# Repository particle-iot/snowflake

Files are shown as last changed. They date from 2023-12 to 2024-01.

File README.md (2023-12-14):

# Particle Snowflake

Welcome to the repository for the Particle Snowflake
, a limited edition [Particle P2](https://store.particle.io/products/p2-wi-fi-module-cut-tape-x10) powered PCBA in the form of a snowflake. The Snowflake provides a seasonal light show and plays a classic holiday tune.

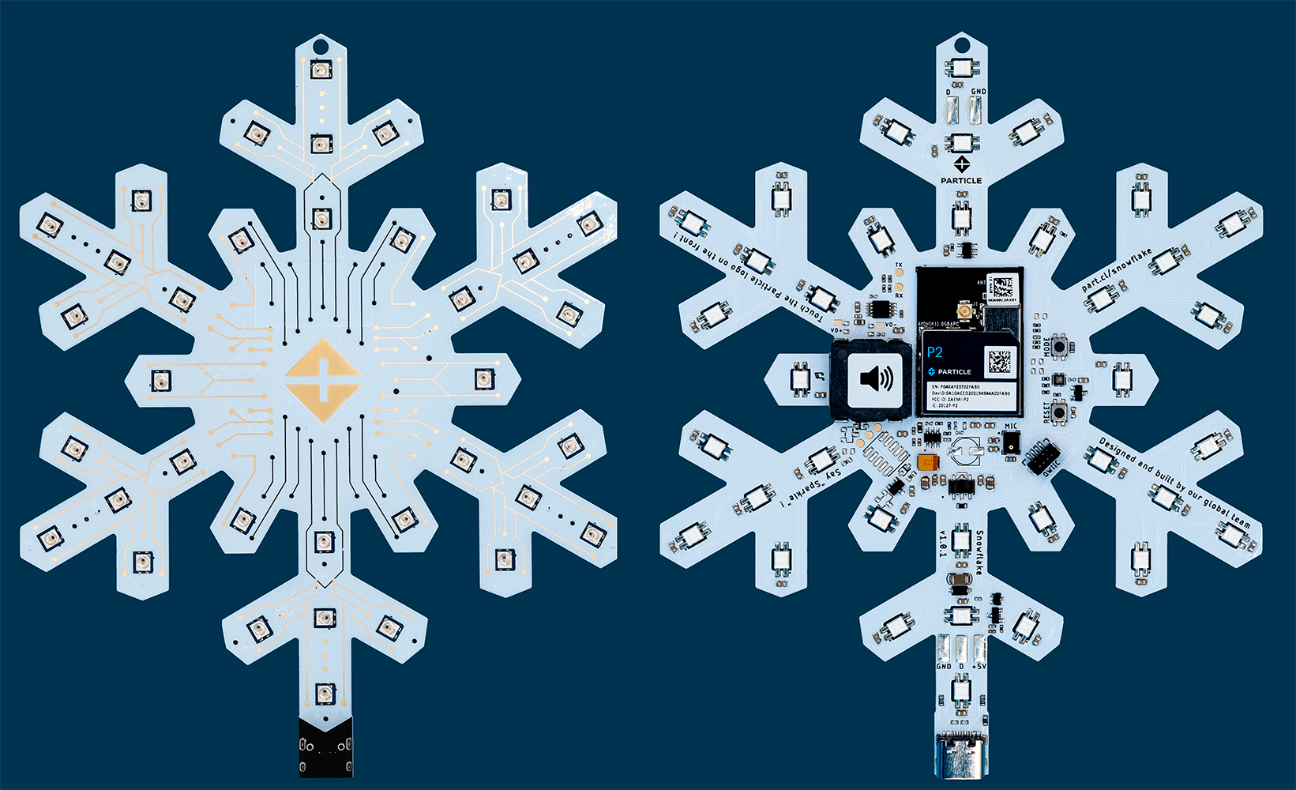
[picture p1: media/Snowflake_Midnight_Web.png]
PCBA


This repository contains all of the firmware and hardware assets required to build the Particle Snowflake.

## Features

The Particle Snowflake has the following components to provide a complete experience straight out of the box:

- 36 individually addressable RGB LEDs to create various colors, patterns, and effects
- Onboard speaker to play festive tunes
- PDM microphone to enable additional features

## Repository Contents

This repository consists of a firmware folder, a hardware folder, and an assets folder.

### Firmware Folder

The firmware folder contains the source code and MP3 asset files that drive the operation of the Particle Snowflake. These include:

- Source code for the application firmware
- Various libraries to support the LEDs, audio and MP3 playback, capacitive touch button drivers, etc.
- MP3 asset files with preloaded message and holiday song

### Hardware Folder

The hardware folder contains detailed design files that can be used for manufacturing the Particle Snowflake. These include:

- Schematic files for the PCBA
- BRD files for the PCBA
- [A comprehensive Bill of Materials (BOM)](./hardware/schematic-pcb/snowflake-hw-v1.0.1/snowflake v1.01 Bom .xlsx)
- Illustrator files for the silkscreen artwork

### Asset Folder

The asset folder contains images and a video illustrating various aspects of the Particle Snowflake. These include:

- [Front of PCBA](./media/Snowflake_Front_Midnight.png)
- [Back of PCBA](./media/Snowflake_Back_Midnight.png)
- [Video of the various light patterns](./media/Snowflake_Action.mp4)

## Usage

Feel free to use these designs as a reference for creating your own Particle Snowflake or use them directly in your designs. 

## Contributing

As an open-source project, we encourage contributions and suggestions. If you have an idea for an improvement or notice a bug, please open an issue or submit a pull request.

## License

This project is open source and available under the [Apache License 2.0](LICENSE).

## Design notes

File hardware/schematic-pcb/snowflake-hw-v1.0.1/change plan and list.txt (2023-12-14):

PCB
done 1, all points were changed from 0.6mm to 0.9 mm 
done 2, Add www.particle.io - size 40mil
done 3, Add the Particle with the logo - biggest size possible
done 4, Reduce the size of the label snowflake v0.0.2 to 40mil
done 5. Fix music symbol 
done 6. Adding in a hole in the PCB at the top to allow someone to put a little ornament hook (linked) through to hang on a tree?
done 7, Chang the Version to  Snowflake 1.0.1
done 8, Move P2 1.5 mm to the left
9, Check USB d+d-  impedance 
10. put the text “Hello” on one of the snowflake arms
11. Text 1  Designed and built by our global team
12. Text 2   Say “Sparkle” !
13. Touch the Particle logo on the front !
done 14. Particle Logo and Name: 
done 15，finish artwork silk-screen and soldermask

sch 
done 1, Change R26 to NC
done 2, Change R25 to  pull-up
done 3, Delete R13
done 4, Add 2  Jump  resistance for Speaker VO- VO+,  Default short connection in PCB,  can cut it off with a knife if you want to open the Speaker
done 5, Add 2  FS-1540

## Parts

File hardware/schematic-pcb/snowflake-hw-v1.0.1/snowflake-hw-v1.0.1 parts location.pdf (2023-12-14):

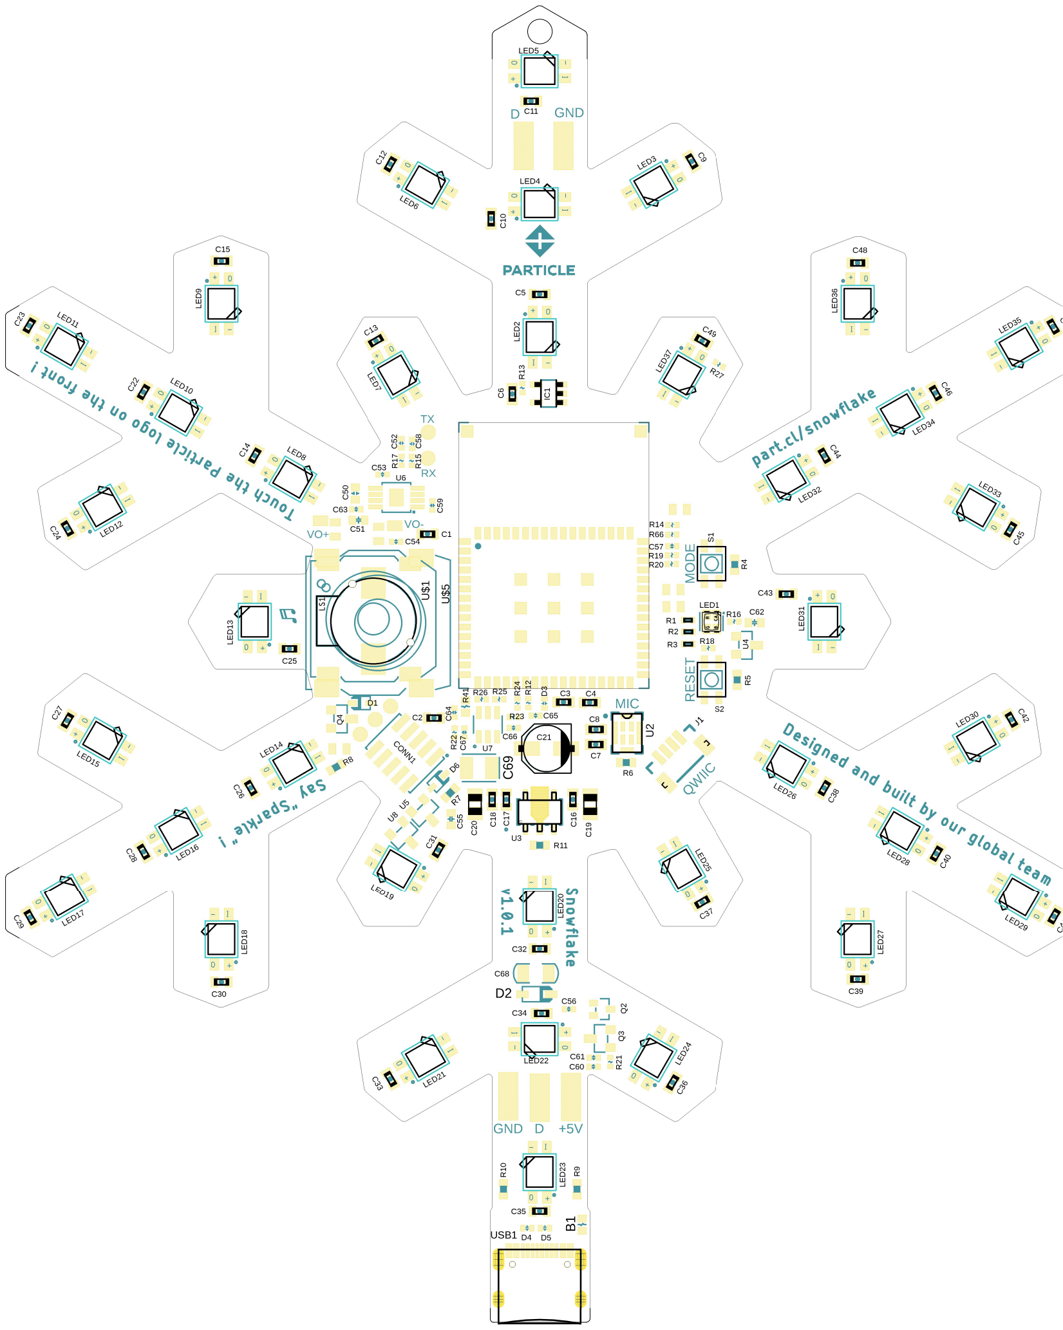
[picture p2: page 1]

C23 C29

LED5

C41

47

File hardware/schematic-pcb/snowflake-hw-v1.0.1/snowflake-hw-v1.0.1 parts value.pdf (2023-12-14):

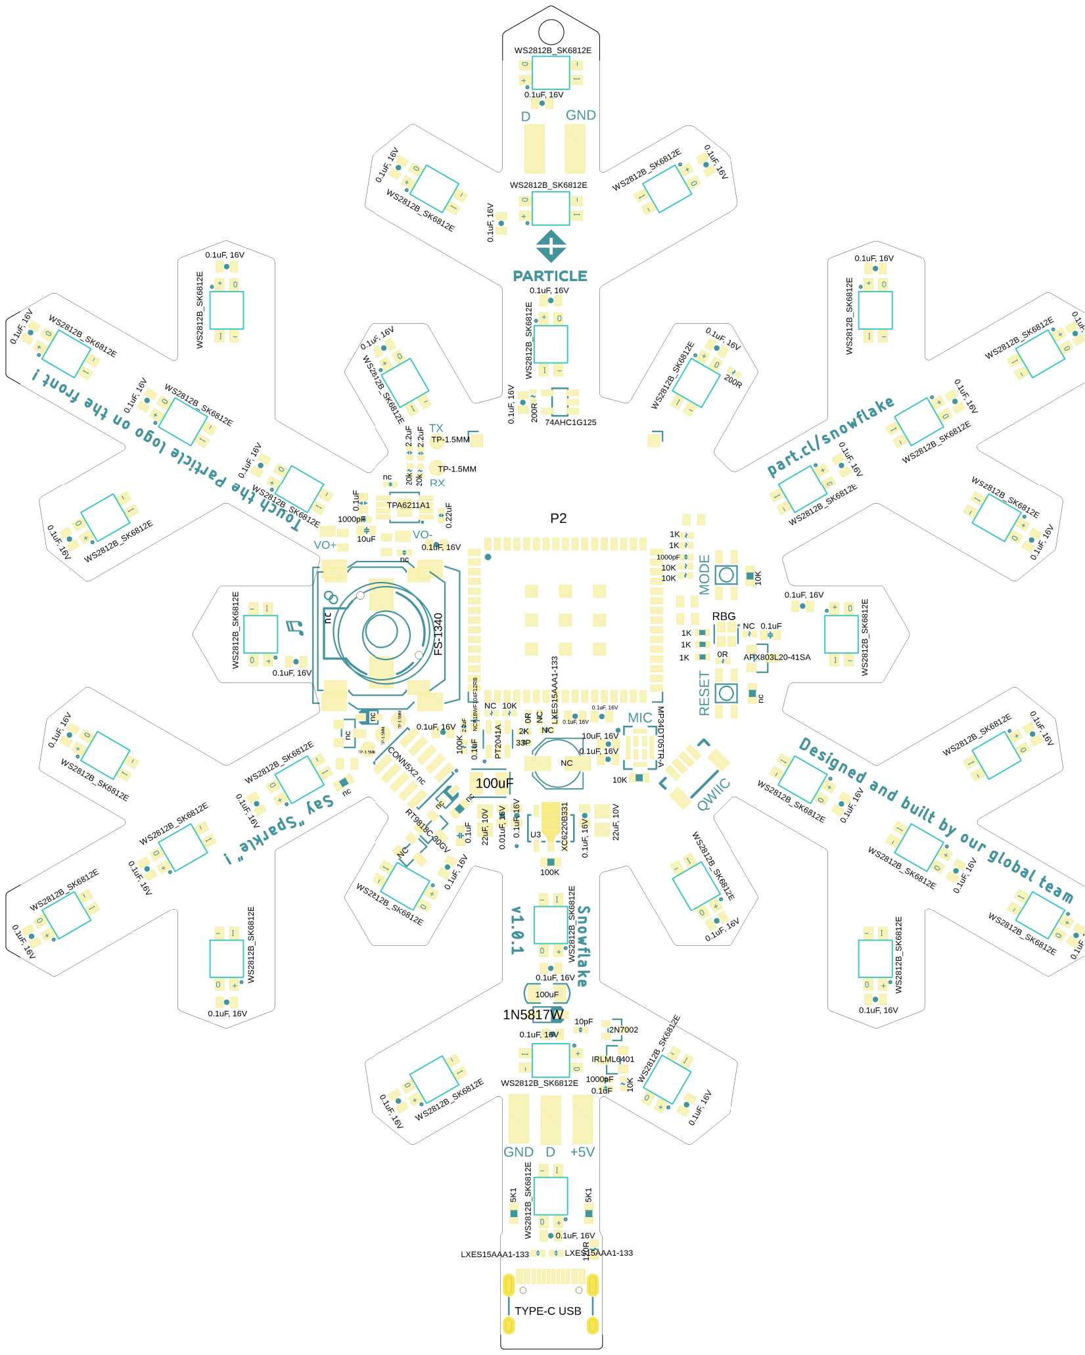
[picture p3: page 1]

0.1uF, 1

0.1uF,

WS2812B_SK6812E

0.1uF, 16V

0.1uF, 16V

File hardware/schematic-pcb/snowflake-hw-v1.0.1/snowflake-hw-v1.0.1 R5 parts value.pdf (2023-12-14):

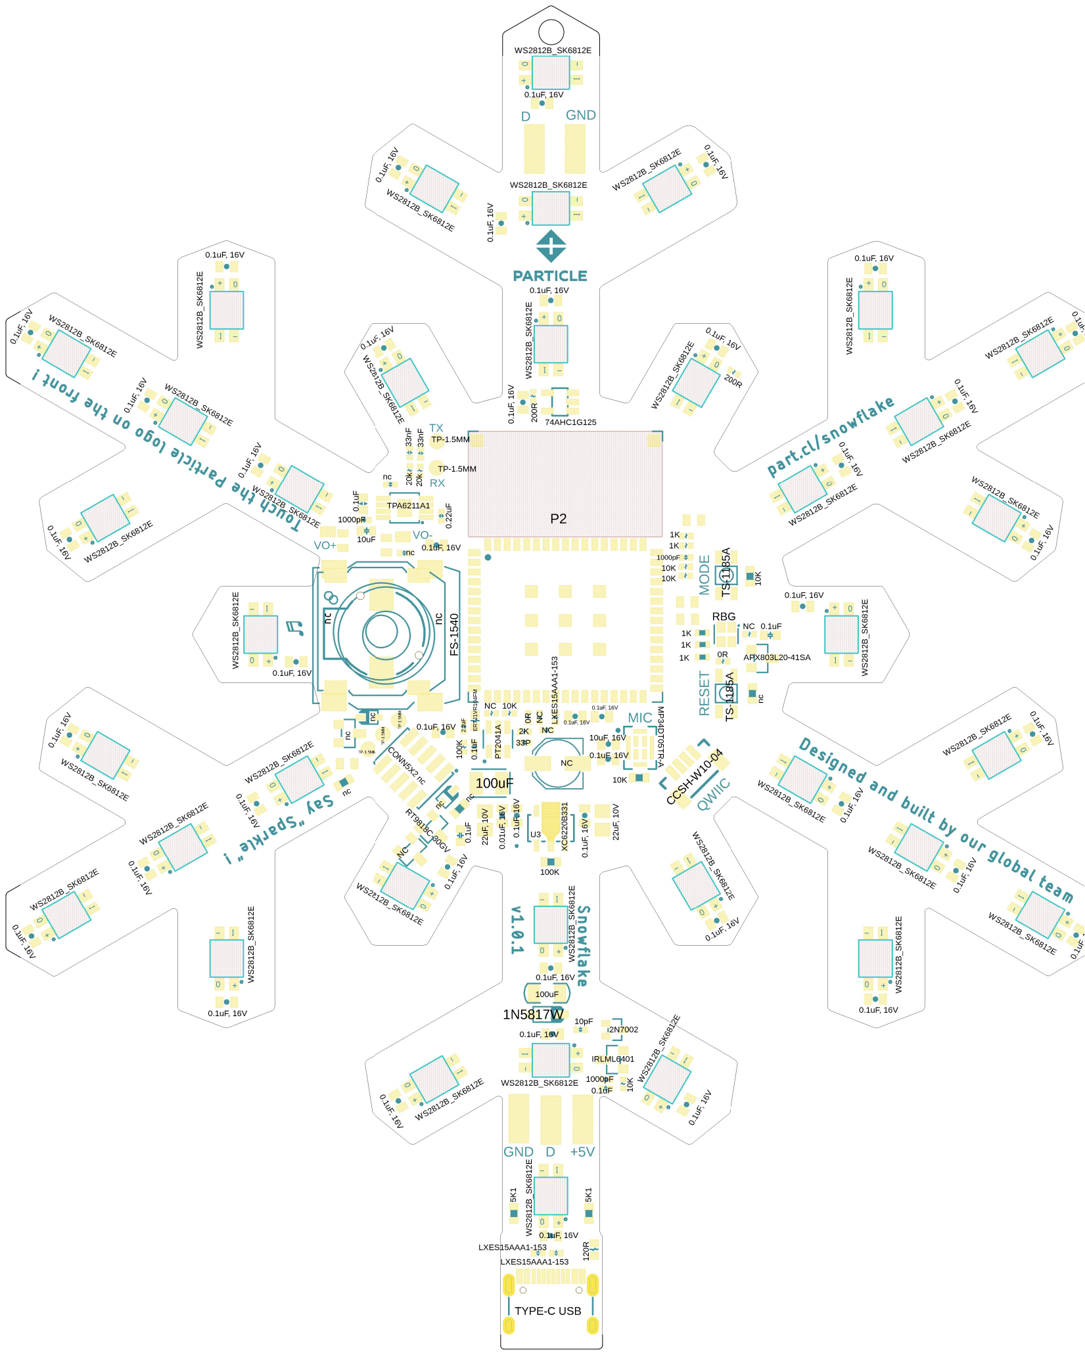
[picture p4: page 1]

0.1uF, 1

0.1uF,

WS2812B_SK6812E

0.1uF, 16V

0.1uF, 16V

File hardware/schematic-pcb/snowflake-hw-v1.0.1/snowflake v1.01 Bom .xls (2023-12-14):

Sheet: Sheet1
Part | list e | xported | from Y:/work/snowflake/SCH | and PCB/snowflake-hw-v1.0.1/贴 | 片图/sno | wf | lake-hw-v1.0.1 R5.sch at 2023/11/9 上午11:26
Qty | Value |  | Device | Package | Parts |  |  | Descript | ion COLOR COPYRIGHT
1 |  |  | CONN_04SMD4 | JST04_1MM_VERT | J1 |  |  | Multi co | nnection point. Often used as Generic Header-pin footprint for 0.1 inch spaced/style header connections BLACK
2 |  |  | TAC_SWITCHSMD | TACTILE_SWITCH_SMD | S1, S2 |  |  | SMD Tact | iile Switch
1 |  |  | USB_C16PIN | USB-C-16P | USB1 |  |  | USB Type | C 16Pin Connector
1 | 0.01uF | , 16V | CAP_0.01UF_25V_0603 | C0603_P | C18 |  |  | Particle | Capacitors
2 | 0.1uF |  | CAP0402 | C-0402 | C60, C67 |  |  | CAP
2 | 0.1uF |  | CAP0603A | C-0603A | C55, C62 |  |  | CAP
1 | 0.1uF |  | CAPC0603 | C0603 | C50 |  |  | CAP
44 | 0.1uF, | 16V | CAP_0.1UF_16V_0603 | C0603_P | C1, C2, C | 3, | C4, C5, C6, C7, C9, C10, C11, C12, C13, C14, C15, C16, C17, C22, C23, C24, C25, C26, C27, C28, C29, C30, C31, C32, C33, C34, C35, C36, C37, C38, C39, C40, C41, C42, C43, C44, C45, C46, C47, C48, C49 | Particle | Capacitors
1 | 0.22uF |  | CAP0402 | C-0402 | C59 |  |  | CAP
2 | 0R |  | RES0402S | R-0402S | R18, R24 |  |  | RES
3 | 1000pF |  | CAP0402 | C-0402 | C57, C61, | C | 63 | CAP
1 | 100K |  | RES0402S | R-0402S | R22 |  |  | RES
1 | 100K |  | RES_100K_0603 | R0603_P | R11 |  |  | Particle | Resistors
1 | 100uF |  | CAP-ECASE_B | CASE-B | C69
1 | 100uF |  | CAPC1206 | C1206 | C68 |  |  | CAP
4 | 10K |  | RES0402S | R-0402S | R19, R20, | R | 21, R25 | RES
2 | 10K |  | RES_10K_0603 | R0603_P | R4, R6 |  |  | Particle | Resistors
1 | 10pF |  | CAP0402 | C-0402 | C56 |  |  | CAP
1 | 10uF |  | CAP0603A | C-0603A | C51 |  |  | CAP
1 | 10uF, | 16V | CAP_10UF_16V_0603 | C0603_P | C8 |  |  | Particle | Capacitors
1 | 120R |  | L | R-0603A | B1
2 | 1K |  | RES0402S | R-0402S | R14, R66 |  |  | RES
3 | 1K |  | RES_1K_0402 | R0402_P | R1, R2, R | 3 |  | Particle | Resistors
1 | 1N5817 | W | DIODESOD123 | SOD-123 | D2 |  |  | DIODE
1 | 2.2uF |  | CAP0402 | C-0402 | C64 |  |  | CAP
2 | 200R |  | RES0402S | R-0402S | R13, R27 |  |  | RES
2 | 20k |  | RES0402S | R-0402S | R15, R17 |  |  | RES
2 | 22uF, | 10V | C-EUC0805 | C0805 | C19, C20 |  |  | CAPACITO | R, European symbol
1 | 2K |  | RES0402S | R-0402S | R23 |  |  | RES
1 | 2N7002 |  | NMOSSOT323 | SOT323 | Q2 |  |  | NMOS
1 | 33P |  | CAP0402 | C-0402 | C66 |  |  | CAP
2 | 33nF |  | CAP0402A | C0402 | C52, C58 |  |  | CAP
2 | 5K1 |  | RES_0603 | R0603_P | R9, R10 |  |  | Particle | Resistors
1 | 74AHC1 | G125 | 74AHC1G125 | SOT23-5L | IC1
1 | APX803 | L20-41S | A APX803XXX-XXSASOT-2 | 3 SOT-23 | U4
1 | CONN5X | 2 nc | CONN5X2 | CONN5X2_1.27 | CONN1 |  |  | 5x2 pin | JTAG connector for Particle mesh dev kits
1 | ERTJ1V | R104FM | RESR0603A | R-0603A | R41 |  |  | RES
1 | FS-154 | 0 | SEPAKER15X15MM | KLJ-01504T | U$5
1 | IRLML6 | 401 | PMOS | SOT-23 | Q3 |  |  | PMOS
6 | JMP_06 | 03_NC | JMP_0603_NC | JMP_0603_NC | U$2, U$3, | U | $4, U$6, U$7, U$15
3 | LXES15 | AAA1-15 | 3 ESD | C0402 | D3, D4, D | 5
1 | MP34DT | 05TR-A | MP34DT05TR-A | MP34DT05TR-A_STM | U2 |  |  |  | Copyright (C) 2023 Ultra Librari
1 | NC |  | APX803XXX-XXSASOT-2 | 3 SOT-23 | U8
1 | NC |  | CAP0402 | C-0402 | C65 |  |  | CAP
1 | NC |  | CPOL-USC | PANASONIC_C | C21 |  |  | POLARIZE | D CAPACITOR, American symbol
3 | NC |  | RES0402S | R-0402S | R12, R16, | R | 26 | RES
1 | NC |  | SEPAKER | KJL-01304T(13X13MM) | U$1
1 | P2 |  | P2 | P2 | U1 |  |  | Particle | P2
1 | PT2041 | A | PT2041A | SOT-23-6 | U7
1 | RGB-LE | D-CLMVB | #NAME? | B PLCC4-2MM-RGB | LED1 |  |  | CREE CLM | VB-FKA RGB LED 2mm x 2mm
1 | RT9818 | C-30GV | RT9818C | SOT-23 | U5
5 | TP-1.5 | MM | TP-1.5MM | TP | TP1, TP5, | T | P6, TP7, TP8
2 | TP1.0X | 1.5 | TP1.0X1.5 | TP-1.0X1.5 | VO+, VO-
5 | TP2X5M | M | TP2X5MM | TP_2X5MM | +5V_EX, D | AT | A, DATA1, GND, GND115
1 | TPA621 | 1A1 | TPA6211A1 | MSOP-8 | U6
36 | WS2812 | B_SK681 | 2E WS2812B_SK6812E | NEO3535_REVERSE | LED2, LED | 3, | LED4, LED5, LED6, LED7, LED8, LED9, LED10, LED11, LED12, LED13, LED14, LED15, LED16, LED17, LED18, LED19, LED20, LED21, LED22, LED23, LED24, LED25, LED26, LED27, LED28, LED29, LED30, LED31, LED32, LED33, LED34, LED35, LED36, LED37
1 | XC6220 | B331PR- | G XC6220B331PR-GSOT-8 | 9-5_TOR-M SOT-89-5_TOR-M | U3 |  |  |  | Copyright (C) 2022 Ultra Librari
1 | nc |  | BUZZER-SMD | BUZZER-CCV | LS1 |  |  | Buzzer
2 | nc |  | CAP0402 | C-0402 | C53, C54 |  |  | CAP
2 | nc |  | DIODESOD323 | SOD-323 | D1, D6 |  |  | DIODE
1 | nc |  | NMOSSOT-23 | SOT-23 | Q4 |  |  | NMOS
1 | nc |  | RES_100K_0603 | R0603_P | R8 |  |  | Particle | Resistors
1 | nc |  | RES_10K_0603 | R0603_P | R5 |  |  | Particle | Resistors
1 | nc |  | RES_1K_0603 | R0603_P | R7 |  |  | Particle | Resistors

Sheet: SNOWFLAKE-PCBA MO bom R2
Item Export
Run by
Name: Vincent Li
Email: vincent@particle.io
Workspace: Particle IO Production
Date: Nov 08, 2023
Run Description: Item Number:SNOWFLAKE-PCBA, Item Name:Holiday Snowflake PCBA, Revision:3
level | item_number | item_name | item_category | quantity | reference_designator | bom_notes | vendor_1 | vendor item number_1 | manufacturer_1 | manufacturer_item_number_1 | manufacturer_2 | manufacturer_item_number_2 | sub_type | sub_rank
0 | SNOWFLAKE-PCBA | Holiday Snowflake PCBA | Printed Circuit Board Assembly
1 | 120-00014 | CAP CER 100UF 10V X5R 1206 20% | Capacitor | 1 | C68 |  |  |  | Murata Electronics | GRM31CR61A107ME05L
1 | 120-00066 | CAP CER 220nF 16V X7R 0402 10% | Capacitor | 1 | C59 |  |  |  | Fenghua (HK) Electronics Ltd. | 0402B224K160NT
1 | 120-00067 | CAP CER 33nF 50V X7R 10% 0402 | Capacitor | 2 | C52,C58 |  |  |  | YAGEO | CC0402KRX7R9BB333
1 | 125-00021 | CONN HEADER SMD 4POS 1MM | Connector | 1 | J1 |  | Kaweei Technology Co Limited | CCSH-W10-04-BK-RC | Kaweei Technology Co Limited | CCSH-W10-04-BK-RC
1 | 140-00053 | DIGITAL RGB LED 0.2W 3.2x2.8x1.8mm SMD middle board mount | Diode | 36 | LED2,LED3,LED4,LED5,LED6,LED7,LED8,LED9,LED10,LED11,LED12,LED13,LED14,LED15,LED16,LED17,LED18,LED19,LED20,LED21,LED22,LED23,LED24,LED25,LED26,LED27,LED28,LED29,LED30,LED31,LED32,LED33,LED34,LED35,LED36,LED37 |  |  |  | Dongguan OPSCO Optoelectronics Co.,LTD | SK6812MINI-E
1 | 140-00055 | TVS DIODE 4VWM 0.05pF@1MHz 0402 | Diode | 3 | D3,D4,D5 |  |  |  | Murata Electronics | LXES15AAA1-153
1 | 150-00067 | IC BUFFER NON-INVERT 6V SC74A/SOT-753 | IC | 1 | IC1 |  |  |  | Nexperia USA Inc. | 74HC1G125GV,125
1 | 150-00068 | MIC MEMS DIGITAL PDM OMNI -26DB | IC | 1 | U2 |  |  |  | STMicroelectronics | MP34DT05TR-A
1 | 150-00069 | IC TOUCH SENSOR 1KEY SOT23-6 | IC | 1 | U7 |  |  |  | PinTeng Technology Co.,Ltd | PT2041AT6
1 | 150-00070 | IC SUPERVISOR 1 CHANNEL SOT23-3 | IC | 1 | U5 |  |  |  | Richtek USA Inc. | RT9818C-30GV
1 | 150-00071 | IC REG LINEAR 3.3V 1A SOT89-5 | IC | 1 | U3 |  |  |  | Torex Semiconductor Ltd | XC6220B331PR-G
1 | 150-00072 | IC AMP CLASS AB MONO 3.1W 8MSOP | IC | 1 | U6 |  |  |  | Texas Instruments | TPA6211A1DGNR
1 | 150-00073 | IC SUPERVISOR 1 CHANNEL SOT23-3 | IC | 1 | U4 |  |  |  | Diodes Incorporated | APX803L20-41SA-7
1 | 160-00013 | SPEAKER 8OHM 0.5W MAX TOP PORT 87DB SMD | Misc. Electrical | 1 | U$5 |  |  |  | Taizhou Fu Sheng Electronic Technology Co., Ltd. | FS-1540
1 | 175-00048 | FR-4 PCB 138.8x112.6x1.6mm Tg150 4layers, 1/0.5/0.5/1oz, WHT oil, BLK silk, ENIG | Printed Circuit Board | 1
1 | 180-00049 | RES 5.1K OHM 1% 1/10W 0603 | Resistor | 2 | R9,R10 |  |  |  | YAGEO | RC0603FR-075K1L
1 | P2REEL | P2 Wi-Fi Module, Reel [x600] | Final Assembly | 1 | U1 |  |  |  | Wistron Neweb Corporation | 81DHSK11.G01
1 | PC-201501 | SMD 16PIN TYPE-C USB2.0 | Connector | 1 | USB1 |  |  |  | ZHAOJIN - EUV Electronics Co., Ltd | EUT-S009-BN-B-R
1 | PT-200001 | RES SMD 100K OHM 1% 1/16W 0402 | Resistor | 1 | R22 |  |  |  | YAGEO | RC0402FR-07100KL
1 | PT-200002 | RES SMD 1K OHM 5% 1/16W 0402 | Resistor | 5 | R1,R2,R3,R14,R66 |  |  |  | Fenghua (HK) Electronics Ltd. | RC-02W102JT | YAGEO | RC0402JR-071KP
1 | PT-200020 | Tactile Switch, Black Button 1.8mm height | Switch | 2 | S1,S2 |  |  |  | HAOYU (HONG KONG) LIMITED | TS-1185A-020C
1 | PT-200082 | CAP CER 0.1uF 16V X7R 0603 10% | Capacitor | 47 | C1,C2,C3,C4,C5,C6,C7,C9,C10,C11,C12,C13,C14,C15,C16,C17,C22,C23,C24,C25,C26,C27,C28,C29,C30,C31,C32,C33,C34,C35,C36,C37,C38,C39,C40,C41,C42,C43,C44,C45,C46,C47,C48,C49,C50,C55,C62 |  |  |  | Fenghua (HK) Electronics Ltd. | 0603B104K160NT
1 | PT-200110 | CAP CER 10nF 50V X7R 0603 10% | Capacitor | 1 | C18 |  | ABO Electronics (SHENZHEN) Co. Ltd | PT-200110 | Fenghua (HK) Electronics Ltd. | 0603B103K500NT
1 | PT-200139 | CAP CER 10uF 16V X5R 0603 20% | Capacitor | 2 | C8,C51 |  | ABO Electronics (SHENZHEN) Co. Ltd | PT-200139 | Fenghua (HK) Electronics Ltd. | 0603X106M160NT
1 | PT-200184 | CAP CER 2.2uF 6.3V X5R 0402 10% Low ESR<70mohms | Capacitor | 1 | C64 |  | UNIVERSAL MICROELECTRONICS CO.,LTD | PT-200184 | YAGEO | CC0402KRX5R5BB225
1 | PT-200197 | RES SMD 0R OHM 5% 1/16W 0402 | Resistor | 2 | R18,R24 |  |  |  | Fenghua (HK) Electronics Ltd. | RC-02000JT
1 | PT-200477 | RES SMD 10K OHM 1% 1/10W 0603 | Resistor | 2 | R4,R6 |  | ABO Electronics (SHENZHEN) Co. Ltd | PT-200477 | YAGEO | RC0603FR-0710KL
1 | PT-200690 | CAP CER 0.1UF 25V X7R 0402 20% | Capacitor | 2 | C60,C67 |  | ABO Electronics (SHENZHEN) Co. Ltd | PT-200690 | Murata Electronics | GRM155R71E104ME14
1 | PT-200691 | CAP CER 1000PF 50V C0G/NP0 0402 5% | Capacitor | 3 | C57,C61,C63 |  | ABO Electronics (SHENZHEN) Co. Ltd | PT-200691 | Murata Electronics | GRM1555C1H102JA01
1 | PT-200699 | CAP CER 22uF 10V X5R 0805 20% | Capacitor | 2 | C19,C20 |  | ABO Electronics (SHENZHEN) Co. Ltd | PT-200699 | YAGEO | CC0805MKX5R6BB226
1 | PT-200700 | NRND - CAP CER 33PF 50V C0G/NP0 0402 5% | Capacitor | 1 | C66 |  | ABO Electronics (SHENZHEN) Co. Ltd | PT-200700 | Murata Electronics | GRM1555C1H330JA01D
1 | PT-200705 | RES SMD 2K OHM 1% 1/16W 0402 | Resistor | 1 | R23 |  |  |  | YAGEO | RC0402FR-072KL
1 | PT-200708 | N-MOS 60V,115mA SC-70 ROHS | IC | 1 | Q2 |  |  |  | Leshan Radio Company, Ltd. | L2N7002WT1G
1 | PT-200709 | P-MOS -12V 4.3A SOT23 ROHS | IC | 1 | Q3 |  |  |  | Infineon Technologies | IRLML6401TRPBF
1 | PT-200722 | NRND - CAP CER 10pF 50V C0G(NP0 ) 0402 5% | Capacitor | 1 | C56 |  | ABO Electronics (SHENZHEN) Co. Ltd | PT-200722 | Murata Electronics | GRM1555C1H100JA01D
1 | PT-200805 | RES SMD 10K OHM 1% 1/16W 0402 | Resistor | 4 | R19,R20,R21,R25 |  | ABO Electronics (SHENZHEN) Co. Ltd | PT-200805 | YAGEO | RC0402FR-0710KL
1 | PT-200821 | LED RGB, Common Anode, Clear, 4PLCC SMD ROHS | Diode | 1 | LED1 |  |  |  | Cree Inc. | CLMVC-FKA-CA1E1L81BB7C3C3
1 | PT-200933 | RES SMD 20K OHM 1% 1/16W 0402 | Resistor | 2 | R15,R17 |  | ABO Electronics (SHENZHEN) Co. Ltd | PT-200933 | ABO Electronics (SHENZHEN) Co. Ltd | 0402WGF0203TCE
1 | PT-200934 | RES SMD 220R OHM 5% 1/16W 0402 | Resistor | 2 | R13,R27 |  |  |  | UNIROYAL ELECTRONICS INDUSTRY CO., LTD. | 0402WGJ0221TCE
1 | PT-201009 | Schottky Diode VF=0.45V SOD123F | Diode | 1 | D2 |  |  |  | JIANGSU CHANGJIANG ELECTRONICS TECHNOLOGY CO., LTD | B5817WL
1 | PT-201206 | RES SMD 100K OHM 1% 1/10W 0603 | Resistor | 1 | R11 |  |  |  | VISHAY | CRCW0603100KFKEA
1 | PT-201400 | FERRITE BEAD 120 OHM 0603 1LN | Inductor | 1 | B1 |  |  |  | Murata Electronics | BLM18PG121SZ1D
1 | PT-201487 | POLY TA SMD B case 100UF 6.3V 20% | Capacitor | 1 | C69 |  |  |  | AVX Corporation | TAJB107M006RNJ
1 | PT-201566 | THERM NTC 100KOHM 4200K 0603 1% | Resistor | 1 | R41 |  |  |  | Particle | ERTJ1VR104FM
Generated for Particle IO Production by Arena. All information contained in this document is proprietary and confidential.

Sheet: SNOWFLAKE-PCBA MO bom R1
Item Export
Run by
Name: Vincent Li
Email: vincent@particle.io
Workspace: Particle IO Production
Date: Nov 07, 2023
Run Description: Item Number:SNOWFLAKE-PCBA, Item Name:Holiday Snowflake PCBA, Revision:2
level | item_number | item_name | item_category | quantity | reference_designator | bom_notes | vendor_1 | vendor item number_1 | manufacturer_1 | manufacturer_item_number_1 | manufacturer_2 | manufacturer_item_number_2 | manufacturer_3 | manufacturer_item_number_3 | sub_type | sub_rank
0 | SNOWFLAKE-PCBA | Holiday Snowflake PCBA | Printed Circuit Board Assembly
1 | 120-00014 | CAP CER 100UF 10V X5R 1206 20% | Capacitor | 1 | C68 |  |  |  | Murata Electronics | GRM31CR61A107ME05L
1 | 120-00066 | CAP CER 220nF 16V X7R 0402 10% | Capacitor | 1 | C59 |  |  |  | Fenghua (HK) Electronics Ltd. | 0402B224K160NT
1 | 120-00067 | CAP CER 33nF 50V X7R 10% 0402 | Capacitor | 2 | C52,C58 |  |  |  | YAGEO | CC0402KRX7R9BB333
1 | 125-00021 | CONN HEADER SMD 4POS 1MM | Connector | 1 | J1 |  | Kaweei Technology Co Limited | CCSH-W10-04-BK-RC | Kaweei Technology Co Limited | CCSH-W10-04-BK-RC
1 | 140-00053 | DIGITAL RGB LED 0.2W 3.2x2.8x1.8mm SMD middle board mount | Diode | 36 | LED2,LED3,LED4,LED5,LED6,LED7,LED8,LED9,LED10,LED11,LED12,LED13,LED14,LED15,LED16,LED17,LED18,LED19,LED20,LED21,LED22,LED23,LED24,LED25,LED26,LED27,LED28,LED29,LED30,LED31,LED32,LED33,LED34,LED35,LED36,LED37 |  |  |  | Dongguan OPSCO Optoelectronics Co.,LTD | SK6812MINI-E
1 | 140-00055 | TVS DIODE 4VWM 0.05pF@1MHz 0402 | Diode | 3 | D3,D4,D5 |  |  |  | Murata Electronics | LXES15AAA1-153
1 | 150-00067 | IC BUFFER NON-INVERT 6V SC74A/SOT-753 | IC | 1 | IC1 |  |  |  | Nexperia USA Inc. | 74HC1G125GV,125
1 | 150-00068 | MIC MEMS DIGITAL PDM OMNI -26DB | IC | 1 | U2 |  |  |  | STMicroelectronics | MP34DT05TR-A
1 | 150-00069 | IC TOUCH SENSOR 1KEY SOT23-6 | IC | 1 | U7 |  |  |  | PinTeng Technology Co.,Ltd | PT2041AT6
1 | 150-00070 | IC SUPERVISOR 1 CHANNEL SOT23-3 | IC | 1 | U5 |  |  |  | Richtek USA Inc. | RT9818C-30GV
1 | 150-00071 | IC REG LINEAR 3.3V 1A SOT89-5 | IC | 1 | U3 |  |  |  | Torex Semiconductor Ltd | XC6220B331PR-G
1 | 150-00072 | IC AMP CLASS AB MONO 3.1W 8MSOP | IC | 1 | U6 |  |  |  | Texas Instruments | TPA6211A1DGNR
1 | 150-00073 | IC SUPERVISOR 1 CHANNEL SOT23-3 | IC | 1 | U4 |  |  |  | Diodes Incorporated | APX803L20-41SA-7
1 | 160-00013 | SPEAKER 8OHM 0.5W MAX TOP PORT 87DB SMD | Misc. Electrical | 1 | U$1 | 位置改为U$5 |  |  | Taizhou Fu Sheng Electronic Technology Co., Ltd. | FS-1540
1 | 175-00048 | FR-4 PCB 138.8x112.6x1.6mm Tg150 4layers, 1/0.5/0.5/1oz, WHT oil, BLK silk, ENIG | Printed Circuit Board | 1
1 | P2REEL | P2 Wi-Fi Module, Reel [x600] | Final Assembly | 1 | U1 |  |  |  | Wistron Neweb Corporation | 81DHSK11.G01
1 | PC-201501 | SMD 16PIN TYPE-C USB2.0 | Connector | 1 | X1 | 位置需要修改为USB1 |  |  | ZHAOJIN - EUV Electronics Co., Ltd | EUT-S009-BN-B-R
1 | PT-200001 | RES SMD 100K OHM 1% 1/16W 0402 | Resistor | 1 | R22 |  |  |  | YAGEO | RC0402FR-07100KL
1 | PT-200002 | RES SMD 1K OHM 5% 1/16W 0402 | Resistor | 3 | R1,R2,R3 | 增加R14, R66，数量改为5 |  |  | Fenghua (HK) Electronics Ltd. | RC-02W102JT | YAGEO | RC0402JR-071KP
1 | PT-200020 | Tactile Switch, Black Button 1.8mm height | Switch | 2 | S1,S2 |  |  |  | HAOYU (HONG KONG) LIMITED | TS-1185A-020C
1 | PT-200082 | CAP CER 0.1uF 16V X7R 0603 10% | Capacitor | 47 | C1,C2,C3,C4,C5,C6,C7,C9,C10,C11,C12,C13,C14,C15,C16,C17,C22,C23,C24,C25,C26,C27,C28,C29,C30,C31,C32,C33,C34,C35,C36,C37,C38,C39,C40,C41,C42,C43,C44,C45,C46,C47,C48,C49,C50,C55,C62 |  |  |  | Fenghua (HK) Electronics Ltd. | 0603B104K160NT
1 | PT-200087 | RES SMD 1K OHM 5% 1/10W 0603 | Resistor | 2 | R14,R66 | 删除，R14, R66改为0402封装 |  |  | Fenghua (HK) Electronics Ltd. | RS-03K102JT | Walsin Technology Corporation | WR06X102 JTL | YAGEO | RC0603JR-071KL
1 | PT-200110 | CAP CER 10nF 50V X7R 0603 10% | Capacitor | 1 | C18 |  | ABO Electronics (SHENZHEN) Co. Ltd | PT-200110 | Fenghua (HK) Electronics Ltd. | 0603B103K500NT
1 | PT-200139 | CAP CER 10uF 16V X5R 0603 20% | Capacitor | 2 | C8,C51 |  | ABO Electronics (SHENZHEN) Co. Ltd | PT-200139 | Fenghua (HK) Electronics Ltd. | 0603X106M160NT
1 | PT-200184 | CAP CER 2.2uF 6.3V X5R 0402 10% Low ESR<70mohms | Capacitor | 1 | C64 |  | UNIVERSAL MICROELECTRONICS CO.,LTD | PT-200184 | YAGEO | CC0402KRX5R5BB225
1 | PT-200197 | RES SMD 0R OHM 5% 1/16W 0402 | Resistor | 2 | R18,R24 |  |  |  | Fenghua (HK) Electronics Ltd. | RC-02000JT
1 | PT-200477 | RES SMD 10K OHM 1% 1/10W 0603 | Resistor | 2 | R4,R6 |  | ABO Electronics (SHENZHEN) Co. Ltd | PT-200477 | YAGEO | RC0603FR-0710KL
1 | PT-200690 | CAP CER 0.1UF 25V X7R 0402 20% | Capacitor | 2 | C60,C67 |  | ABO Electronics (SHENZHEN) Co. Ltd | PT-200690 | Murata Electronics | GRM155R71E104ME14
1 | PT-200691 | CAP CER 1000PF 50V C0G/NP0 0402 5% | Capacitor | 3 | C57,C61,C63 |  | ABO Electronics (SHENZHEN) Co. Ltd | PT-200691 | Murata Electronics | GRM1555C1H102JA01
1 | PT-200699 | CAP CER 22uF 10V X5R 0805 20% | Capacitor | 2 | C19,C20 |  | ABO Electronics (SHENZHEN) Co. Ltd | PT-200699 | YAGEO | CC0805MKX5R6BB226
1 | PT-200700 | NRND - CAP CER 33PF 50V C0G/NP0 0402 5% | Capacitor | 1 | C66 |  | ABO Electronics (SHENZHEN) Co. Ltd | PT-200700 | Murata Electronics | GRM1555C1H330JA01D
1 | PT-200705 | RES SMD 2K OHM 1% 1/16W 0402 | Resistor | 1 | R23 |  |  |  | YAGEO | RC0402FR-072KL
1 | PT-200708 | N-MOS 60V,115mA SC-70 ROHS | IC | 1 | Q2 |  |  |  | Leshan Radio Company, Ltd. | L2N7002WT1G
1 | PT-200709 | P-MOS -12V 4.3A SOT23 ROHS | IC | 1 | Q3 |  |  |  | Infineon Technologies | IRLML6401TRPBF
1 | PT-200722 | NRND - CAP CER 10pF 50V C0G(NP0 ) 0402 5% | Capacitor | 1 | C56 |  | ABO Electronics (SHENZHEN) Co. Ltd | PT-200722 | Murata Electronics | GRM1555C1H100JA01D
1 | PT-200805 | RES SMD 10K OHM 1% 1/16W 0402 | Resistor | 4 | R19,R20,R21,R25 |  | ABO Electronics (SHENZHEN) Co. Ltd | PT-200805 | YAGEO | RC0402FR-0710KL
1 | PT-200821 | LED RGB, Common Anode, Clear, 4PLCC SMD ROHS | Diode | 1 | LED1 |  |  |  | Cree Inc. | CLMVC-FKA-CA1E1L81BB7C3C3
1 | PT-200934 | RES SMD 220R OHM 5% 1/16W 0402 | Resistor | 2 | R13,R27 |  |  |  | UNIROYAL ELECTRONICS INDUSTRY CO., LTD. | 0402WGJ0221TCE
1 | PT-201009 | Schottky Diode VF=0.45V SOD123F | Diode | 1 | D2 |  |  |  | JIANGSU CHANGJIANG ELECTRONICS TECHNOLOGY CO., LTD | B5817WL
1 | PT-201206 | RES SMD 100K OHM 1% 1/10W 0603 | Resistor | 1 | R11 |  |  |  | VISHAY | CRCW0603100KFKEA
1 | PT-201400 | FERRITE BEAD 120 OHM 0603 1LN | Inductor | 1 | B1 |  |  |  | Murata Electronics | BLM18PG121SZ1D
1 | PT-201487 | POLY TA SMD B case 100UF 6.3V 20% | Capacitor | 1 | C69 |  |  |  | AVX Corporation | TAJB107M006RNJ
1 | PT-201531 | RES SMD 5.1K OHM 1% 1/16W 0402 | Resistor | 2 | R9,R10 | 要改用0603的料 |  |  | YAGEO | RC0402FR-075K1L
1 | PT-201566 | THERM NTC 100KOHM 4200K 0603 1% | Resistor | 1 | R41 |  |  |  | Particle | ERTJ1VR104FM
 |  | RES SMD 20K OHM 1% 1/16W 0402 | Resistor | 2 | R15, R17 | 增加
Generated for Particle IO Production by Arena. All information contained in this document is proprietary and confidential.

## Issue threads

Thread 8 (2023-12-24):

Builds & Flashes but doesn't Run

niabassey, 2023-12-24:
Building this from source in Particle Workbench gets as far as a successful build and flash and when the flash finishes the P2 even connects to WiFi, but that's it.  The LED animation stays frozen in it's last state and there no serial output (usually it give TFLite stats).

Flashing using https://setup.particle.io/?app=particle-snowflake brings it back up, but half the fun is getting to code this thing.

Are there particular build instructions to get a working locally built firmware image?

svanhoutte, 2023-12-25:
@niabassey How did you manage to compile, I get a SRAM overflowed. I m trying the 5.6.0 firmware, and code straight from the repo. I tried in the workbench and on docker same error.

> /root/.particle/toolchains/gcc-arm/10.2.1/bin/../lib/gcc/arm-none-eabi/10.2.1/../../../../arm-none-eabi/bin/ld: /workspace/target/workspace_fi.elf section `.bss' will not fit in region `SRAM'
/root/.particle/toolchains/gcc-arm/10.2.1/bin/../lib/gcc/arm-none-eabi/10.2.1/../../../../arm-none-eabi/bin/ld: region `SRAM' overflowed by 4 bytes
collect2: error: ld returned 1 exit status
make[1]: Leaving directory `/firmware/modules/tron/user-part'
make[1]: *** [/workspace/target/workspace_fi.elf] Error 1
make: *** [modules/tron/user-part] Error 2

niabassey, 2023-12-26:
I was able to compile on Windows but the application doesn't run.  I tried on Ubuntu and I got the same SRAM overflowed error :(

jhewitt0, 2024-01-04:
I'm unable to compile on Windows 11 using CLI or Workbench. Help please...

`particle compile p2 . --saveTo firmware.zip --target 5.5.0`
> Compile failed: Compiler timed out or encountered an error

If I tell Workbench to do a Cloud Compile I just get
> Compile failed: Compiler timed out or encountered an error
	at makeError (c:\Users\j_hew\.vscode\extensions\particle.particle-vscode-core-1.16.13\node_modules\execa\lib\error.js:59:11)
	at handlePromise (c:\Users\j_hew\.vscode\extensions\particle.particle-vscode-core-1.16.13\node_modules\execa\index.js:114:26)
	at process.processTicksAndRejections (node:internal/process/task_queues:95:5)

What is the correct way to compile the code?

Thanks

svanhoutte, 2024-01-04:
@jhewitt0 you should try a local compile from the bench.

mrlambchop, 2024-01-06:
Hey folks,

Apologies - there is a random bug in the makefile that breaks the compilation at semi-random.

We have a pending release that fixes this but it got stuck behind the holidays - not great timing I know.

To work around this, you can:

- clone device OS GitHub repo into a local folder
- git checkout -b fix/ram-calc-section-alignment origin/fix/ram-calc-section-alignment
- git submodules init
- git submodule update --recursive

Then open the project in Workbench and in the settings, set the setting:

Particle: Custom Device OSLocation to the path. Make sure the path is fully qualified.

Then in workbench, you can compile / flash the project and it won't randomly fail. I'll post back when the device OS release is out.

Thanks

Nick.

svanhoutte, 2024-01-08:
@mrlambchop I confirm the workaround works.
This link help to get the workbench setup. https://docs.particle.io/getting-started/developer-tools/workbench-faq/

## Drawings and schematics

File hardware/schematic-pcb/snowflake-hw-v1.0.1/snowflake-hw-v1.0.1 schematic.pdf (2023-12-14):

### FS-1340 nc

FS-1540

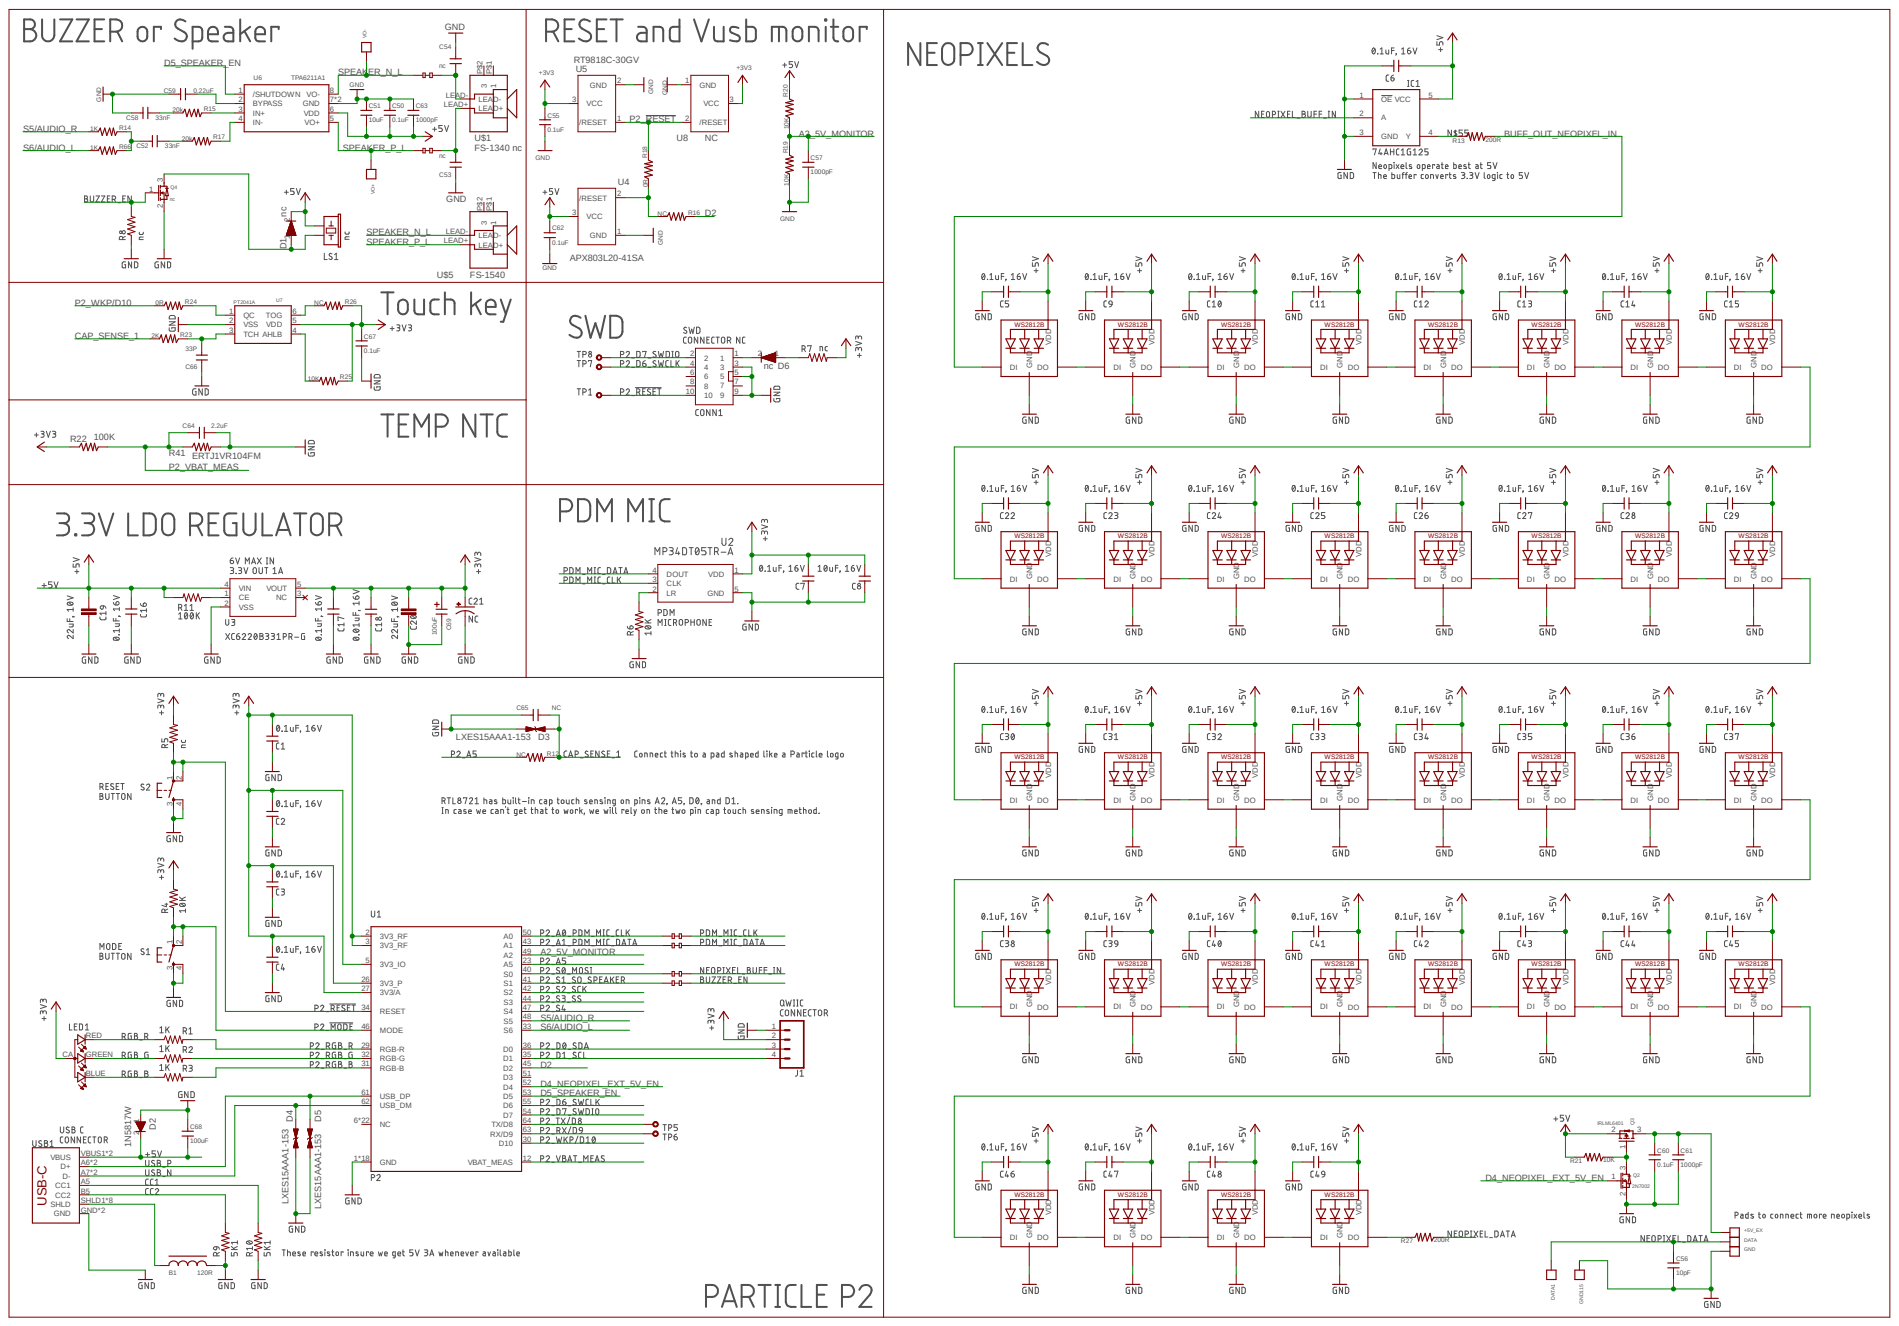
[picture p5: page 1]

DI GND DO VDD

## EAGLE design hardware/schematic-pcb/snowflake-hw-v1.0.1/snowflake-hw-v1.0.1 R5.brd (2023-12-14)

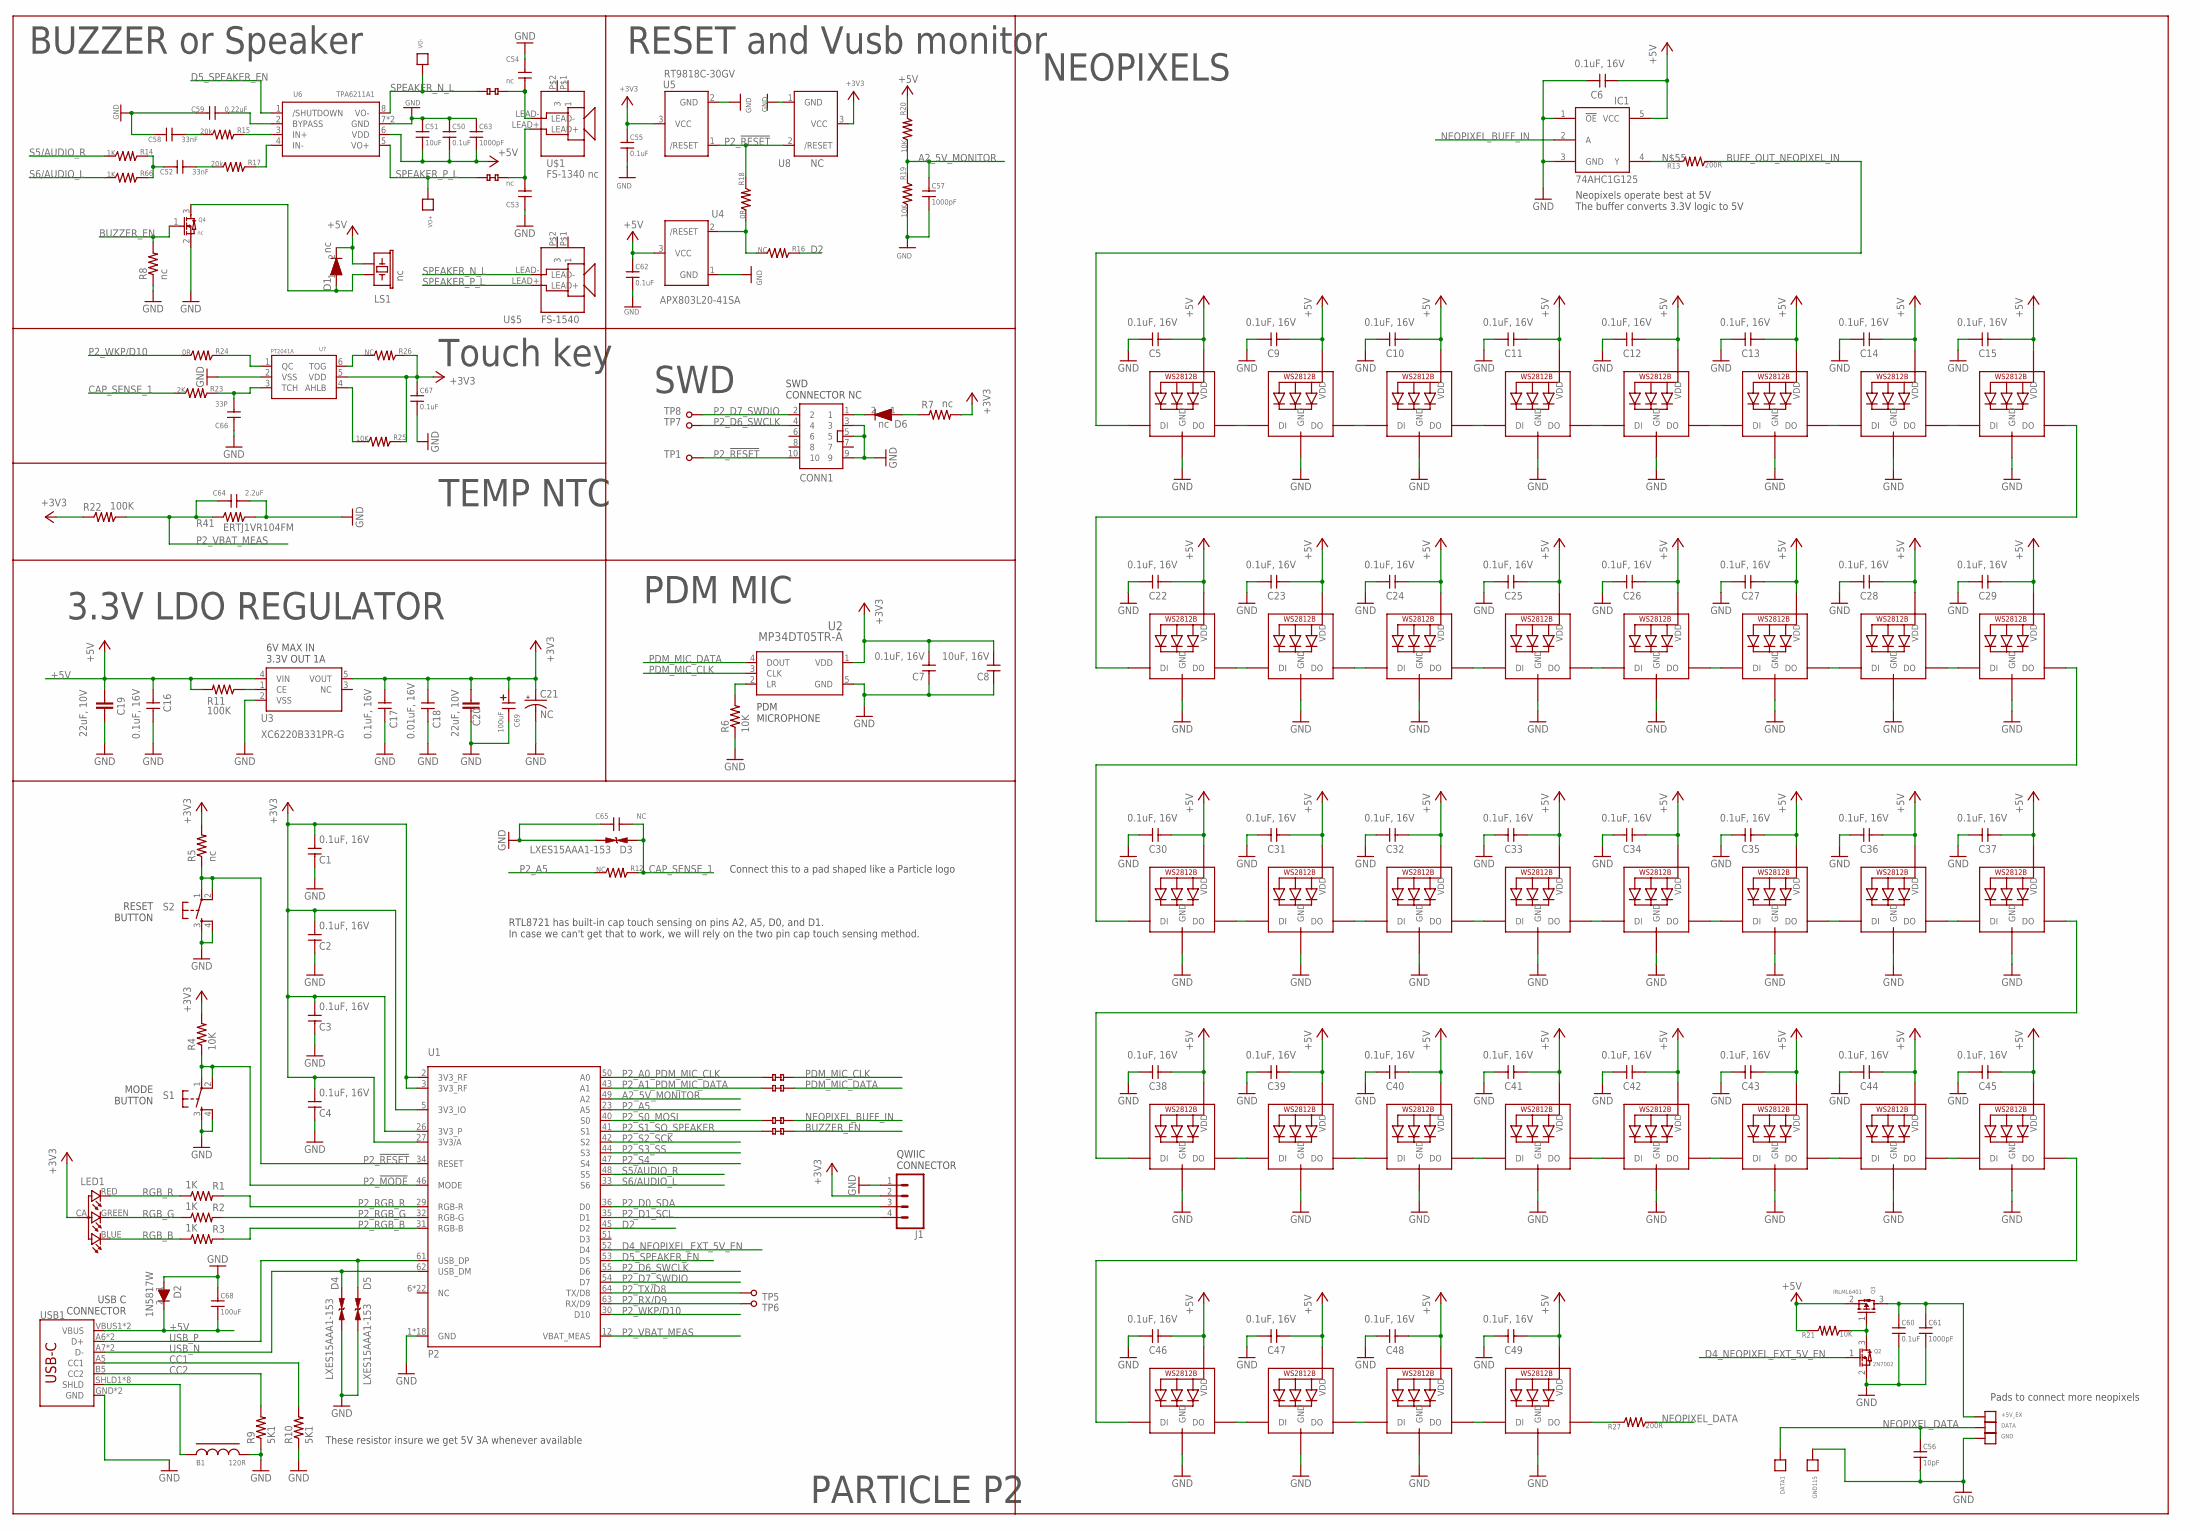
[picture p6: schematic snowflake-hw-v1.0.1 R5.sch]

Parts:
+5V_EX: TP2X5MM; TP_2X5MM
B1: 120R; R-0603A
C1, C2, C3, C4, C5, C6, C7, C9, C10, C11, C12, C13, C14, C15, C16, C17, C22, C23, C24, C25, C26, C27, C28, C29, C30, C31, C32, C33, C34, C35, C36, C37, C38, C39, C40, C41, C42, C43, C44, C45, C46, C47, C48, C49: 0.1uF, 16V; C0603_P
C8: 10uF, 16V; C0603_P
C18: 0.01uF, 16V; C0603_P
C19, C20: 22uF, 10V; C0805
C21: NC; PANASONIC_C
C50: 0.1uF; C0603
C51: 10uF; C-0603A
C52, C58: 33nF; C0402
C53, C54: nc; C-0402
C55, C62: 0.1uF; C-0603A
C56: 10pF; C-0402
C57, C61, C63: 1000pF; C-0402
C59: 0.22uF; C-0402
C60, C67: 0.1uF; C-0402
C64: 2.2uF; C-0402
C65: NC; C-0402
C66: 33P; C-0402
C68: 100uF; C1206
C69: 100uF; CASE-B
CONN1: CONN5X2 nc; CONN5X2_1.27
D1, D6: nc; SOD-323
D2: 1N5817W; SOD-123
D3, D4, D5: LXES15AAA1-153; C0402
DATA, DATA1: TP2X5MM; TP_2X5MM
GND, GND115: TP2X5MM; TP_2X5MM
IC1: 74AHC1G125; SOT23-5L
J1: CONN_04SMD4; JST04_1MM_VERT
LED1: RGB-LED-CLMVB-FKARGB; PLCC4-2MM-RGB
LED2, LED3, LED4, LED5, LED6, LED7, LED8, LED9, LED10, LED11, LED12, LED13, LED14, LED15, LED16, LED17, LED18, LED19, LED20, LED21, LED22, LED23, LED24, LED25, LED26, LED27, LED28, LED29, LED30, LED31, LED32, LED33, LED34, LED35, LED36, LED37: WS2812B_SK6812E; NEO3535_REVERSE
LS1: nc; BUZZER-CCV
Q2: 2N7002; SOT323
Q3: IRLML6401; SOT-23
Q4: nc; SOT-23
R1, R2, R3: 1K; R0402_P
R4, R6: 10K; R0603_P
R5, R7, R8: nc; R0603_P
R9, R10: 5K1; R0603_P
R11: 100K; R0603_P
R12, R16, R26: NC; R-0402S
R13, R27: 200R; R-0402S
R14, R66: 1K; R-0402S
R15, R17: 20k; R-0402S
R18, R24: 0R; R-0402S
R19, R20, R21, R25: 10K; R-0402S
R22: 100K; R-0402S
R23: 2K; R-0402S
R41: ERTJ1VR104FM; R-0603A
S1, S2: TAC_SWITCHSMD; TACTILE_SWITCH_SMD
TP1, TP5, TP6, TP7, TP8: TP-1.5MM; TP
U1: P2
U2: MP34DT05TR-A; MP34DT05TR-A_STM
U3: XC6220B331PR-G; SOT-89-5_TOR-M
U4: APX803L20-41SA; SOT-23
U5: RT9818C-30GV; SOT-23
U6: TPA6211A1; MSOP-8
U7: PT2041A; SOT-23-6
U8: NC; SOT-23
U$1: NC; KJL-01304T(13X13MM)
U$2, U$3, U$4, U$6, U$7, U$15: JMP_0603_NC
U$5: FS-1540; KLJ-01504T
USB1: USB_C16PIN; USB-C-16P
VO+: TP1.0X1.5; TP-1.0X1.5
VO-: TP1.0X1.5; TP-1.0X1.5

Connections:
+3V3: C1.1, C2.1, C3.1, C4.1, C7.1, C8.1, C17.2, C18.1, C20.1, C21.+, C55.2, C67.2, C69.P$1 (1), J1.2, LED1.CA (1), R4.2, R5.2, R7.2, R22.1, R25.2, R26.2, U1.2 (3V3_RF), U1.3 (3V3_RF), U1.5 (3V3_IO), U1.26 (3V3_P), U1.27 (3V3/A), U2.1 (VDD), U3.5 (VOUT), U5.3 (VCC), U7.5 (VDD), U8.3 (VCC)
+5V: C5.2, C6.2, C9.2, C10.2, C11.2, C12.2, C13.2, C14.2, C15.2, C16.2, C19.1, C22.2, C23.2, C24.2, C25.2, C26.2, C27.2, C28.2, C29.2, C30.2, C31.2, C32.2, C33.2, C34.2, C35.2, C36.2, C37.2, C38.2, C39.2, C40.2, C41.2, C42.2, C43.2, C44.2, C45.2, C46.2, C47.2, C48.2, C49.2, C50.1, C51.1, C62.2, C63.1, C68.1, D1.2, D2.2, IC1.5 (VCC), LED2.1-VDD (VDD), LED3.1-VDD (VDD), LED4.1-VDD (VDD), LED5.1-VDD (VDD), LED6.1-VDD (VDD), LED7.1-VDD (VDD), LED8.1-VDD (VDD), LED9.1-VDD (VDD), LED10.1-VDD (VDD), LED11.1-VDD (VDD), LED12.1-VDD (VDD), LED13.1-VDD (VDD), LED14.1-VDD (VDD), LED15.1-VDD (VDD), LED16.1-VDD (VDD), LED17.1-VDD (VDD), LED18.1-VDD (VDD), LED19.1-VDD (VDD), LED20.1-VDD (VDD), LED21.1-VDD (VDD), LED22.1-VDD (VDD), LED23.1-VDD (VDD), LED24.1-VDD (VDD), LED25.1-VDD (VDD), LED26.1-VDD (VDD), LED27.1-VDD (VDD), LED28.1-VDD (VDD), LED29.1-VDD (VDD), LED30.1-VDD (VDD), LED31.1-VDD (VDD), LED32.1-VDD (VDD), LED33.1-VDD (VDD), LED34.1-VDD (VDD), LED35.1-VDD (VDD), LED36.1-VDD (VDD), LED37.1-VDD (VDD), LS1.+ (1), Q3.2, R11.2, R20.2, R21.2, U3.4 (VIN), U4.3 (VCC), U6.6 (VDD), USB1.VBUS1 (VBUS), USB1.VBUS2 (VBUS)
A2_5V_MONITOR: C57.2, R19.2, R20.1, U1.49 (A2)
BUFF_OUT_NEOPIXEL_IN: LED2.4-DIN (DI), R13.1
BUZZER_EN: Q4.1, R8.2, U$2.2
CAP_SENSE_1: C65.1, D3.1, R12.2, R23.1
CC1: R10.2, USB1.A5 (CC1)
CC2: R9.2, USB1.B5 (CC2)
D2: R16.2, U1.45 (D2)
D4_NEOPIXEL_EXT_5V_EN: Q2.1, U1.52 (D4)
D5_SPEAKER_EN: U1.53 (D5), U6.1 (/SHUTDOWN)
GND: B1.2, C1.2, C2.2, C3.2, C4.2, C5.1, C6.1, C7.2, C8.2, C9.1, C10.1, C11.1, C12.1, C13.1, C14.1, C15.1, C16.1, C17.1, C18.2, C19.2, C20.2, C21.-, C22.1, C23.1, C24.1, C25.1, C26.1, C27.1, C28.1, C29.1, C30.1, C31.1, C32.1, C33.1, C34.1, C35.1, C36.1, C37.1, C38.1, C39.1, C40.1, C41.1, C42.1, C43.1, C44.1, C45.1, C46.1, C47.1, C48.1, C49.1, C50.2, C51.2, C53.1, C54.2, C55.1, C56.1, C57.1, C58.2, C59.2, C60.1, C61.1, C62.1, C63.2, C64.1, C65.2, C66.1, C67.1, C68.2, C69.P$2 (2), CONN1.3, CONN1.5, CONN1.9, D2.1, D3.2, D4.2, D5.2, GND.P$1, GND115.P$1, IC1.1 (!OE), IC1.3 (GND), J1.1, LED2.3-GND (GND), LED3.3-GND (GND), LED4.3-GND (GND), LED5.3-GND (GND), LED6.3-GND (GND), LED7.3-GND (GND), LED8.3-GND (GND), LED9.3-GND (GND), LED10.3-GND (GND), LED11.3-GND (GND), LED12.3-GND (GND), LED13.3-GND (GND), LED14.3-GND (GND), LED15.3-GND (GND), LED16.3-GND (GND), LED17.3-GND (GND), LED18.3-GND (GND), LED19.3-GND (GND), LED20.3-GND (GND), LED21.3-GND (GND), LED22.3-GND (GND), LED23.3-GND (GND), LED24.3-GND (GND), LED25.3-GND (GND), LED26.3-GND (GND), LED27.3-GND (GND), LED28.3-GND (GND), LED29.3-GND (GND), LED30.3-GND (GND), LED31.3-GND (GND), LED32.3-GND (GND), LED33.3-GND (GND), LED34.3-GND (GND), LED35.3-GND (GND), LED36.3-GND (GND), LED37.3-GND (GND), Q2.2, Q4.2, R6.1, R8.1, R9.1, R10.1, R19.1, R41.2, S1.3, S1.4, S2.3, S2.4, U1.1 (GND), U1.4 (GND), U1.13 (GND), U1.15 (GND), U1.25 (GND), U1.28 (GND), U1.37 (GND), U1.39 (GND), U1.59 (GND), U1.65 (GND), U1.66 (GND), U1.67 (GND), U1.68 (GND), U1.69 (GND), U1.70 (GND), U1.71 (GND), U1.72 (GND), U1.73 (GND), U2.5 (GND), U3.2 (VSS), U4.1 (GND), U5.2 (GND), U6.7 (GND), U6.9 (GND), U7.2 (VSS), U8.1 (GND), USB1.GND, USB1.GND2 (GND)
unnamed: R6.2, U2.2 (LR)
unnamed: LED2.2-DOUT (DO), LED3.4-DIN (DI)
unnamed: LED3.2-DOUT (DO), LED4.4-DIN (DI)
unnamed: LED4.2-DOUT (DO), LED5.4-DIN (DI)
unnamed: LED5.2-DOUT (DO), LED6.4-DIN (DI)
unnamed: LED6.2-DOUT (DO), LED7.4-DIN (DI)
unnamed: LED7.2-DOUT (DO), LED8.4-DIN (DI)
unnamed: LED8.2-DOUT (DO), LED9.4-DIN (DI)
unnamed: D1.1, LS1.- (2), Q4.3
unnamed: R11.1, U3.1 (CE)
unnamed: LED10.2-DOUT (DO), LED11.4-DIN (DI)
unnamed: LED11.2-DOUT (DO), LED12.4-DIN (DI)
unnamed: LED12.2-DOUT (DO), LED13.4-DIN (DI)
unnamed: LED13.2-DOUT (DO), LED14.4-DIN (DI)
unnamed: LED14.2-DOUT (DO), LED15.4-DIN (DI)
unnamed: LED15.2-DOUT (DO), LED16.4-DIN (DI)
unnamed: CONN1.1, D6.2
unnamed: D6.1, R7.1
unnamed: LED16.2-DOUT (DO), LED17.4-DIN (DI)
unnamed: LED9.2-DOUT (DO), LED10.4-DIN (DI)
unnamed: LED24.2-DOUT (DO), LED25.4-DIN (DI)
unnamed: LED23.2-DOUT (DO), LED24.4-DIN (DI)
unnamed: LED22.2-DOUT (DO), LED23.4-DIN (DI)
unnamed: LED21.2-DOUT (DO), LED22.4-DIN (DI)
unnamed: LED20.2-DOUT (DO), LED21.4-DIN (DI)
unnamed: LED19.2-DOUT (DO), LED20.4-DIN (DI)
unnamed: LED18.2-DOUT (DO), LED19.4-DIN (DI)
unnamed: LED25.2-DOUT (DO), LED26.4-DIN (DI)
unnamed: LED26.2-DOUT (DO), LED27.4-DIN (DI)
unnamed: LED27.2-DOUT (DO), LED28.4-DIN (DI)
unnamed: LED28.2-DOUT (DO), LED29.4-DIN (DI)
unnamed: LED29.2-DOUT (DO), LED30.4-DIN (DI)
unnamed: LED30.2-DOUT (DO), LED31.4-DIN (DI)
unnamed: LED31.2-DOUT (DO), LED32.4-DIN (DI)
unnamed: LED32.2-DOUT (DO), LED33.4-DIN (DI)
unnamed: LED17.2-DOUT (DO), LED18.4-DIN (DI)
unnamed: LED34.2-DOUT (DO), LED35.4-DIN (DI)
unnamed: LED35.2-DOUT (DO), LED36.4-DIN (DI)
unnamed: LED36.2-DOUT (DO), LED37.4-DIN (DI)
unnamed: LED33.2-DOUT (DO), LED34.4-DIN (DI)
unnamed: C52.1, R17.1
unnamed: R17.2, U6.4 (IN-)
unnamed: R16.1, R18.1, U4.2 (/RESET)
unnamed: Q2.3, Q3.1, R21.1
unnamed: +5V_EX.P$1, C60.2, C61.2, Q3.3
unnamed: C58.1, R15.1
unnamed: R15.2, U6.3 (IN+)
unnamed: C52.2, R14.2, R66.2
unnamed: C59.1, U6.2 (BYPASS)
unnamed: C66.2, R23.2, U7.3 (TCH)
unnamed: R24.2, U7.1 (QC)
unnamed: R25.1, U7.4 (AHLB)
unnamed: B1.1, USB1.SHLD1 (SHLD), USB1.SHLD2 (SHLD), USB1.SHLD3 (SHLD), USB1.SHLD4 (SHLD), USB1.SHLD5 (SHLD), USB1.SHLD6 (SHLD), USB1.SHLD7 (SHLD), USB1.SHLD8 (SHLD)
unnamed: R26.1, U7.6 (TOG)
unnamed: IC1.4 (Y), R13.2
unnamed: LED37.2-DOUT (DO), R27.2
NEOPIXEL_BUFF_IN: IC1.2 (A), U$15.2
NEOPIXEL_DATA: C56.2, DATA.P$1, DATA1.P$1, R27.1
P2_!MODE: R4.1, S1.1, S1.2, U1.46 (MODE)
P2_!RESET: CONN1.10, R5.1, R18.2, S2.1, S2.2, TP1.TP, U1.34 (RESET), U5.1 (/RESET), U8.2 (/RESET)
P2_A0_PDM_MIC_CLK: U1.50 (A0), U$4.1
P2_A1_PDM_MIC_DATA: U1.43 (A1), U$3.1
P2_A5: R12.1, U1.23 (A5)
P2_D0_SDA: J1.3, U1.36 (D0)
P2_D1_SCL: J1.4, U1.35 (D1)
P2_D6_SWCLK: CONN1.4, TP7.TP, U1.55 (D6)
P2_D7_SWDIO: CONN1.2, TP8.TP, U1.54 (D7)
P2_RGB_B: R3.2, U1.31 (RGB-B)
P2_RGB_G: R2.2, U1.32 (RGB-G)
P2_RGB_R: R1.2, U1.29 (RGB-R)
P2_RX/D9: TP6.TP, U1.63 (RX/D9)
P2_S0_MOSI: U1.40 (S0), U$15.1
P2_S1_SO_SPEAKER: U1.41 (S1), U$2.1
P2_S2_SCK: U1.42 (S2)
P2_S3_SS: U1.44 (S3)
P2_S4: U1.47 (S4)
P2_TX/D8: TP5.TP, U1.64 (TX/D8)
P2_VBAT_MEAS: C64.2, R22.2, R41.1, U1.12 (VBAT_MEAS)
P2_WKP/D10: R24.1, U1.30 (D10)
PDM_MIC_CLK: U2.3 (CLK), U$4.2
PDM_MIC_DATA: U2.4 (DOUT), U$3.2
RGB_B: LED1.BLUE (2), R3.1
RGB_G: LED1.GREEN (3), R2.1
RGB_R: LED1.RED (4), R1.1
S5/AUDIO_R: R14.1, U1.48 (S5)
S6/AUDIO_L: R66.1, U1.33 (S6)
SPEAKER_N_L: C54.1, U6.8 (VO-), U$1.LEAD-, U$5.LEAD-, U$6.1, U$6.2, VO-.P$1
SPEAKER_P_L: C53.2, U6.5 (VO+), U$1.LEAD+, U$5.LEAD+, U$7.1, U$7.2, VO+.P$1
USB_N: D4.1, U1.62 (USB_DM), USB1.A7 (D-), USB1.B7 (D-)
USB_P: D5.1, U1.61 (USB_DP), USB1.A6 (D+), USB1.B6 (D+)

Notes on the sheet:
6V MAX IN 3.3V OUT 1A
RESET BUTTON
MODE BUTTON
QWIIC CONNECTOR
SWD CONNECTOR NC
PDM MICROPHONE
RTL8721 has built-in cap touch sensing on pins A2, A5, D0, and D1. In case we can't get that to work, we will rely on the two pin cap touch sensing method.
Pads to connect more neopixels
3.3V LDO REGULATOR
PDM MIC
BUZZER or Speaker
SWD
NEOPIXELS
PARTICLE P2
USB C CONNECTOR
Neopixels operate best at 5V The buffer converts 3.3V logic to 5V
Connect this to a pad shaped like a Particle logo
These resistor insure we get 5V 3A whenever available
RESET and Vusb monitor
TEMP NTC
Touch key
FS-1340 nc
FS-1540
U$5
U$1

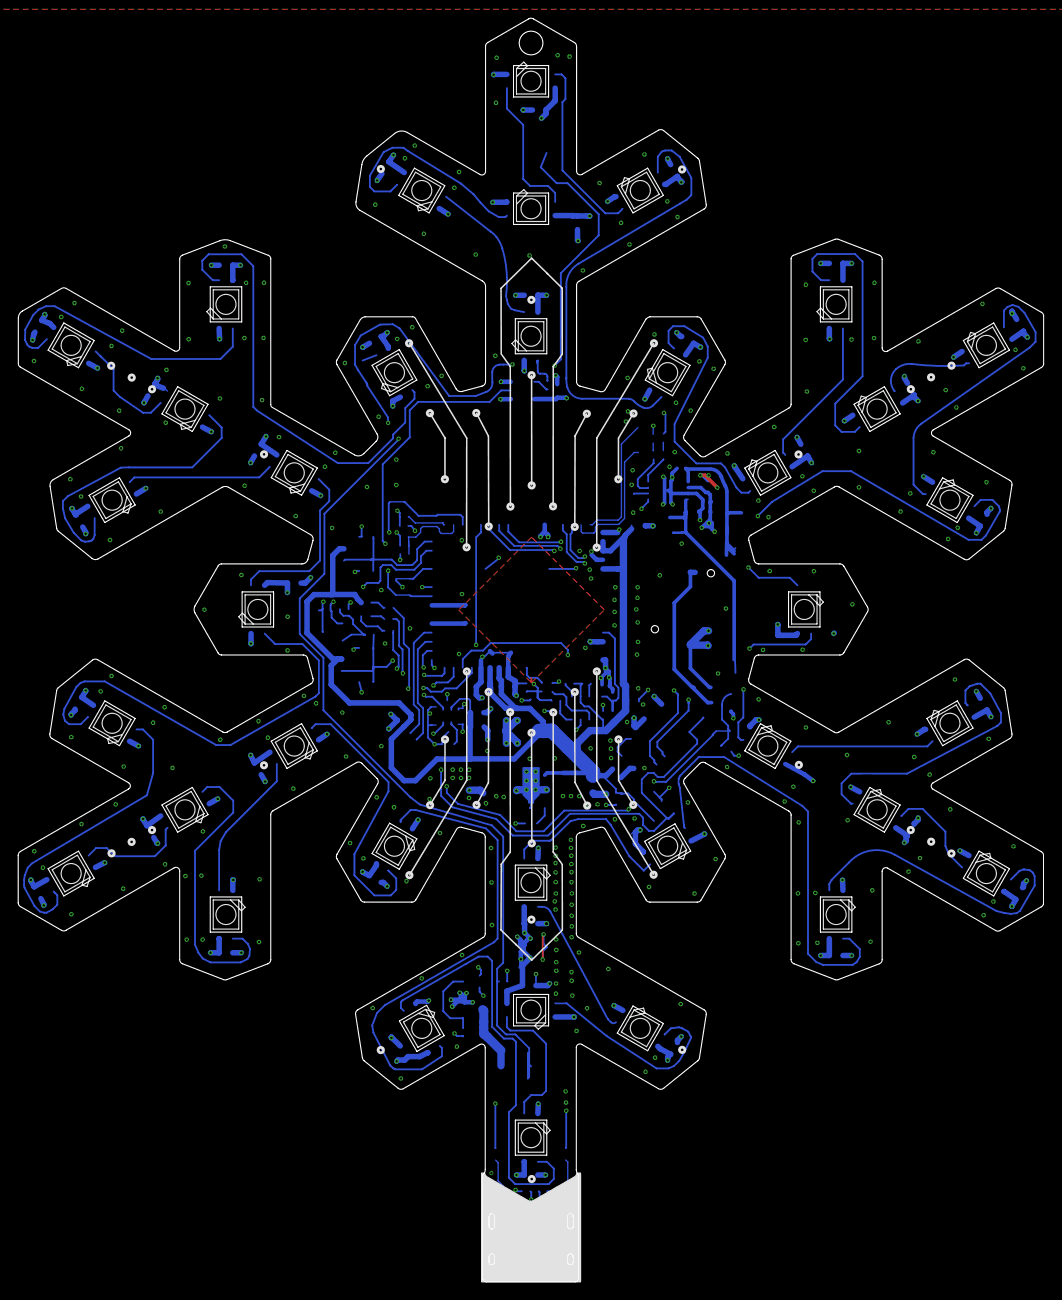
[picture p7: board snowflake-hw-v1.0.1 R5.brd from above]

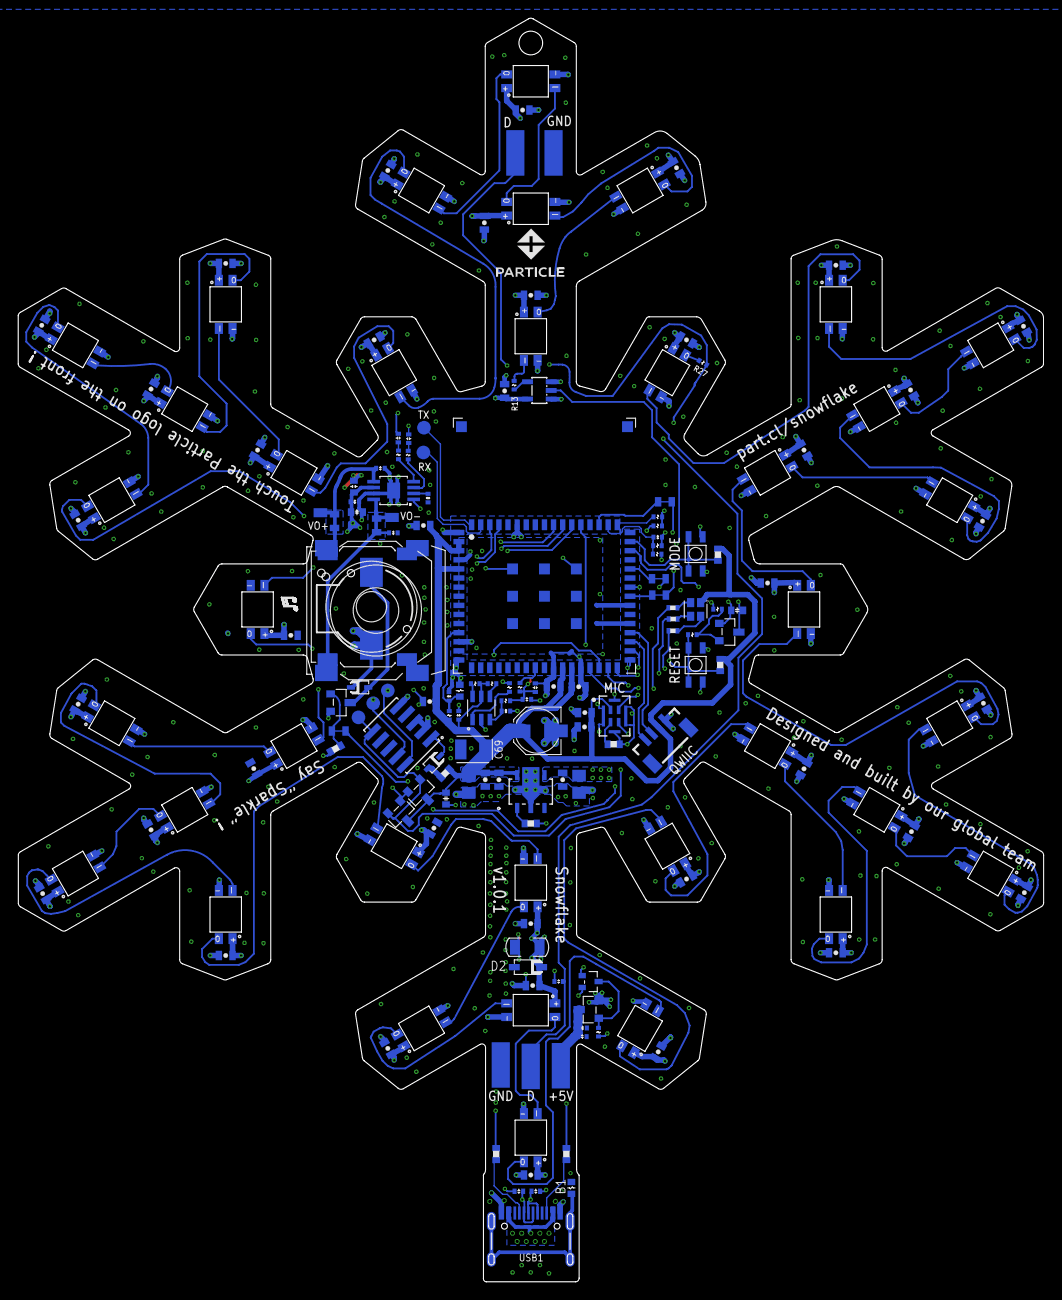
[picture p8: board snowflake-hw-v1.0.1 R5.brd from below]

Board: 4 copper layers, 112.6 x 138.7 mm, 180 parts (144 on the bottom side), 99 nets.

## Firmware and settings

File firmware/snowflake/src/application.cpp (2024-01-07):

#include "Particle.h"

#include "RgbStrip.h"
#include "NtcThermistor.h"
#include "clickButton.h"
#include "Settings.h"
#include "AudioPlayer.h"
#include "MP3Player.h"
#include "TonePlayer.h"
#include "VoicePulse.h"

//#define DEBUG_STARTUP_DELAY
#define SUPPORT_AUDIO_TONE
#define SUPPORT_MP3_PLAYBACK
#define SUPPORT_VOICE_DETECTION

#define WELCOME_VOICE "voice_welcome.mp3"
#define SUPER_STAR_MP3 "super_star.mp3"

#define MINIMP3_IMPLEMENTATION
#include "minimp3/minimp3.h"

//Firmware version 1.2.00
PRODUCT_VERSION(1200);

// Let Device OS manage the connection to the Particle Cloud
SYSTEM_MODE(SEMI_AUTOMATIC);

// Run the application and system concurrently in separate threads
SYSTEM_THREAD(ENABLED);

//enable the reset reason feature
STARTUP(System.enableFeature(FEATURE_RESET_INFO));

//Default to the internall antenna
STARTUP(WiFi.selectAntenna(ANT_INTERNAL));

SerialLogHandler logHandler(LOG_LEVEL_ERROR);

//The particle logo on the front is a button - this is the controller for it
static constexpr int TOUCH_PIN = D10;
ClickButton particleButton(TOUCH_PIN, LOW, CLICKBTN_PULLUP);

//The controller for the LEDs and the mode
RgbStrip *rgbStrip = NULL;
static RgbStrip::MODES_T mode = RgbStrip::MODE_SNOWFLAKE;

//our settings controller
Settings settings = Settings();

//audio interface
AudioPlayer audioPlayer = AudioPlayer();

//mp3 player
MP3Player mp3Player = MP3Player(&audioPlayer);

//tone player
TonePlayer tonePlayer = TonePlayer(&audioPlayer);

//was sparkle detected?
static void sparkleDetectedCallback( void );
static bool sparkleMode = false;

//voice pulse. threshold of .72 is somewhat arbitariily chosen from testing - it might be too high / low
VoicePulse voicePulse = VoicePulse(&audioPlayer, sparkleDetectedCallback, 0.72f);

//list of songs to play and index of the current song
std::vector<String> songs;
uint32_t songIndex = 0;

//forward for the function that controls the mode
static int cloudMode(String command);

static void setMode( RgbStrip::MODES_T newMode ) {
    rgbStrip->setMode(mode);
    settings.set("ledMode", String(mode));
    settings.store();
}


void setup()
{
    // //wait for usb  to connect
    #ifdef DEBUG_STARTUP_DELAY
        waitFor(Serial.isConnected, 10000);

       delay(10000);
    #endif

    rgbStrip = new RgbStrip();

    //load our settings file
    settings.init();

    //get the led mode and set the mode variable
    String ledMode = settings.get("ledMode");
    if (ledMode.length() > 0) {
        mode = (RgbStrip::MODES_T)ledMode.toInt();
        rgbStrip->setMode(mode);
    }

    //configure the touch button
    pinMode(TOUCH_PIN, INPUT_PULLUP);

    // Setup button timers (all in milliseconds / ms)
    // (These are default if not set, but changeable for convenience)
    particleButton.debounceTime   = 20;   // Debounce timer in ms
    particleButton.multiclickTime = 250;  // Time limit for multi clicks
    particleButton.longClickTime  = 1000; // time until "held-down clicks" register

    // Particle Function to control Mode
    Particle.function("Mode", cloudMode);

    // find all mp3 files in the assets system disk and create a list of them for later
    auto assets = System.assetsAvailable();
    for (auto& asset: assets)
    {
        if (asset.name().endsWith(".mp3"))
        {  
            //don't add WELCOME_VOICE or SUPER_STAR_MP3
            if( (asset.name() != WELCOME_VOICE) && (asset.name() != SUPER_STAR_MP3) ) {
                songs.push_back(asset.name());
                //Log.info("Found song: %s", asset.name().c_str());
            }
        }
    }

    //hardware watchdog
    Watchdog.init(WatchdogConfiguration().timeout(10s));
    Watchdog.start();

  #ifdef SUPPORT_AUDIO_TONE
      Log.info("Reset reason: %d", System.resetReason());

      const auto resetReason = System.resetReason();

      switch( resetReason )
      {
          case RESET_REASON_PIN_RESET:
          case RESET_REASON_USER:
          case RESET_REASON_POWER_DOWN:
              //play a two-tone beep boop when booting up only from a cold power on or USB reset
              //tonePlayer.play( TonePlayer::TONE_SEQUENCE_BOOT );

              //play the welcome mp3
              //don't play this in the updated version, but leave the code in here incase someone wants to modify
              //mp3Player.play(WELCOME_VOICE, 100);
          break;
      }
  #endif

  #ifdef SUPPORT_VOICE_DETECTION
      //start the voice pulse
      voicePulse.start();
  #endif

  //Connect to the particle platform!
  //This will run asynchronously
  Particle.connect();
}


bool mp3IsPlaying = false;

void loop()
{
    static bool localSparkleMode = false;

    // Update button state
    particleButton.Update();

    //kick the watchdog
    Watchdog.refresh(); 

    //If we are in 'sparkle' mode, run the basic sparkle animation and play the audio, detecting when it finishes and then resuming the previous animation mode
    if( sparkleMode && !localSparkleMode ) {

        //only start sparkle mode if we are not already playing an MP3
        if( !mp3IsPlaying ) {
            //entering sparkle mode 
            rgbStrip->setMode(RgbStrip::MODE_SPARKLE);

            //start the mp3
            mp3Player.play(SUPER_STAR_MP3, 100, [&](const bool playing){
                mp3IsPlaying = playing;
            });

            localSparkleMode = true;
        }
        else {
            Log.info("MP3 is already playing, not starting sparkle mode");
            sparkleMode = false;
        }
    }
    else if( sparkleMode && localSparkleMode ) {
        //has the mp3 finished?
        if( !mp3IsPlaying ) {
            //exit sparkle mode
            sparkleMode = false;
            localSparkleMode = false;

            //restore the previous led mode
            rgbStrip->setMode(mode);
        }
    }

    //ignore the buttons if we are in sparkle mode
    if( !localSparkleMode ) {
        //switch on particleButton.clicks
        switch( particleButton.clicks ) 
        {
            case 1:
                Log.info("SINGLE click");
                //inc mode
                mode = (RgbStrip::MODES_T)((mode + 1) % RgbStrip::MODE_MAX);

                // don't allow these to be selected by default as its just used for bootup or the secret..
                if( (mode == RgbStrip::MODE_OFF) || (mode == RgbStrip::MODE_SPARKLE) ) { 
                    mode = RgbStrip::MODE_SNOWFLAKE;
                }
                setMode( mode );

                #ifdef SUPPORT_AUDIO_TONE
                    //play a two-tone beep boop when switching the display mode
                    //this will fail if already playing a song
                    tonePlayer.play( TonePlayer::TONE_SEQUENCE_TWO_TONE );
                #endif
            break;

            case 2:
                Log.info("DOUBLE click");
            break;

            case 3:
                Log.info("TRIPLE click");
            break;

            case -1:
                Log.info("SINGLE LONG click");

                #ifdef SUPPORT_MP3_PLAYBACK
                    if( !mp3IsPlaying ) {
                        //play the next song in the list
                        //it allows max of 1 item to be queued and provides a callback
                        mp3Player.play(songs[songIndex], 100,  [&](const bool playing){
                            mp3IsPlaying = playing;
                        });
                        songIndex = (songIndex + 1) % songs.size();
                    }
                #endif
            break;
        }
    }
}

//Note - the sparkle voice detection is disabled by default!
//To enable:
// - View your device in the Particle console
// - On the right side where there are functions listed, find 'settingsWrite'
// - Into this box, please put sparkleEnable=1 and then press Call (making sure your device is online)
// - It will enable this feature on your device.
// - You can also just change bool sparkleEnable = false; to true in the code :)
static void sparkleDetectedCallback( void ) {
    Log.info("Sparkle Detected!");
    bool sparkleEnable = false;

    String sparkleEnableSetting = settings.get("sparkleEnable");
    if (sparkleEnableSetting.length() > 0) {
        //set the sparkleEnable
        sparkleEnable = (bool)sparkleEnableSetting.toInt();
    }

    //set the sparkle mode based on sparkleEnable
    sparkleMode = sparkleEnable;
}

//Cloud Functions
//Contributed by Github user: niabassey
static int cloudMode(String command)
{
    command.toLowerCase();
    
    if(command == "sparkle" || command == "s"){
        Log.info("Particle Cloud: Sparkle Mode!");
        sparkleMode = true;
    }
    
    if(command == "off"){
        Log.info("Particle Cloud: LEDs Off mode");
        mode = RgbStrip::MODE_OFF; 
        setMode(mode);
    }
    
    #ifdef SUPPORT_AUDIO_TONE
        //play a two-tone beep boop for all other mode changes
        //this will fail if already playing a song
        tonePlayer.play( TonePlayer::TONE_SEQUENCE_TWO_TONE );
    #endif
    
    if(command == "next" || command == "n" ){
        Log.info("Particle Cloud: Next mode");
        mode = (RgbStrip::MODES_T)((mode + 1) % RgbStrip::MODE_MAX);

        // don't allow these to be selected by default as its just used for bootup or the secret..
        if( (mode == RgbStrip::MODE_OFF) || (mode == RgbStrip::MODE_SPARKLE) ) { 
            mode = RgbStrip::MODE_SNOWFLAKE;
        }
        setMode(mode);
    }

    if(command == "prev" || command == "p" || command == "previous" ){
        Log.info("Particle Cloud: Prev mode");
        if( (mode == RgbStrip::MODE_OFF) || (mode + 1 == RgbStrip::MODE_OFF) ) {
            //skip over sparkle mode and off mode
            mode = (RgbStrip::MODES_T)((RgbStrip::MODE_MAX) - 2);
        }
        else {
            mode = (RgbStrip::MODES_T)((mode - 1));
        }
        
        setMode(mode);
    }

    if(command == "snowflake"){
        Log.info("Particle Cloud: *Snowflake* mode");
        mode = RgbStrip::MODE_SNOWFLAKE; 
        setMode(mode);
    }

    if(command == "hanukkah"){
        Log.info("Particle Cloud: Hanukkah mode");
        setMode(mode);
    }

    if(command == "rainbow"){
        Log.info("Particle Cloud: Rainbow mode");
        mode = RgbStrip::MODE_RAINBOW; 
        setMode(mode);
    }

    if(command == "chase" || command == "chase holiday"){
        Log.info("Particle Cloud: Chase Holiday mode");
        mode = RgbStrip::MODE_CHASE_HOLIDAY; 
        setMode(mode);
    }
    
    if(command == "circles" || command == "circle" || command == "circles rotate"){
        Log.info("Particle Cloud: Circles Rotate mode");
        mode = RgbStrip::MODE_CIRCLES_ROTATE; 
        setMode(mode);
    }

    if(command == "wave" || command == "wave spinner"){
        Log.info("Particle Cloud: Wave Spinner mode");
        mode = RgbStrip::MODE_WAVE_SPINNER; 
        setMode(mode);
    }

    if(command == "reset"){
        System.reset();
        return 1;
    }

    return -1;
}

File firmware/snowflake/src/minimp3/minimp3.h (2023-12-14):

#ifndef MINIMP3_H
#define MINIMP3_H
/*
    https://github.com/lieff/minimp3
    To the extent possible under law, the author(s) have dedicated all copyright and related and neighboring rights to this software to the public domain worldwide.
    This software is distributed without any warranty.
    See <http://creativecommons.org/publicdomain/zero/1.0/>.
*/
#include <stdint.h>

#define MINIMP3_MAX_SAMPLES_PER_FRAME (1152*2)

typedef struct
{
    int frame_bytes, frame_offset, channels, hz, layer, bitrate_kbps;
} mp3dec_frame_info_t;

typedef struct
{
    float mdct_overlap[2][9*32], qmf_state[15*2*32];
    int reserv, free_format_bytes;
    unsigned char header[4], reserv_buf[511];
} mp3dec_t;

#ifdef __cplusplus
extern "C" {
#endif /* __cplusplus */

void mp3dec_init(mp3dec_t *dec);
#ifndef MINIMP3_FLOAT_OUTPUT
typedef int16_t mp3d_sample_t;
#else /* MINIMP3_FLOAT_OUTPUT */
typedef float mp3d_sample_t;
void mp3dec_f32_to_s16(const float *in, int16_t *out, int num_samples);
#endif /* MINIMP3_FLOAT_OUTPUT */
int mp3dec_decode_frame(mp3dec_t *dec, const uint8_t *mp3, int mp3_bytes, mp3d_sample_t *pcm, mp3dec_frame_info_t *info);

#ifdef __cplusplus
}
#endif /* __cplusplus */

#endif /* MINIMP3_H */
#if defined(MINIMP3_IMPLEMENTATION) && !defined(_MINIMP3_IMPLEMENTATION_GUARD)
#define _MINIMP3_IMPLEMENTATION_GUARD

#include <stdlib.h>
#include <string.h>

#define MAX_FREE_FORMAT_FRAME_SIZE  2304    /* more than ISO spec's */
#ifndef MAX_FRAME_SYNC_MATCHES
#define MAX_FRAME_SYNC_MATCHES      10
#endif /* MAX_FRAME_SYNC_MATCHES */

#define MAX_L3_FRAME_PAYLOAD_BYTES  MAX_FREE_FORMAT_FRAME_SIZE /* MUST be >= 320000/8/32000*1152 = 1440 */

#define MAX_BITRESERVOIR_BYTES      511
#define SHORT_BLOCK_TYPE            2
#define STOP_BLOCK_TYPE             3
#define MODE_MONO                   3
#define MODE_JOINT_STEREO           1
#define HDR_SIZE                    4
#define HDR_IS_MONO(h)              (((h[3]) & 0xC0) == 0xC0)
#define HDR_IS_MS_STEREO(h)         (((h[3]) & 0xE0) == 0x60)
#define HDR_IS_FREE_FORMAT(h)       (((h[2]) & 0xF0) == 0)
#define HDR_IS_CRC(h)               (!((h[1]) & 1))
#define HDR_TEST_PADDING(h)         ((h[2]) & 0x2)
#define HDR_TEST_MPEG1(h)           ((h[1]) & 0x8)
#define HDR_TEST_NOT_MPEG25(h)      ((h[1]) & 0x10)
#define HDR_TEST_I_STEREO(h)        ((h[3]) & 0x10)
#define HDR_TEST_MS_STEREO(h)       ((h[3]) & 0x20)
#define HDR_GET_STEREO_MODE(h)      (((h[3]) >> 6) & 3)
#define HDR_GET_STEREO_MODE_EXT(h)  (((h[3]) >> 4) & 3)
#define HDR_GET_LAYER(h)            (((h[1]) >> 1) & 3)
#define HDR_GET_BITRATE(h)          ((h[2]) >> 4)
#define HDR_GET_SAMPLE_RATE(h)      (((h[2]) >> 2) & 3)
#define HDR_GET_MY_SAMPLE_RATE(h)   (HDR_GET_SAMPLE_RATE(h) + (((h[1] >> 3) & 1) + ((h[1] >> 4) & 1))*3)
#define HDR_IS_FRAME_576(h)         ((h[1] & 14) == 2)
#define HDR_IS_LAYER_1(h)           ((h[1] & 6) == 6)

#define BITS_DEQUANTIZER_OUT        -1
#define MAX_SCF                     (255 + BITS_DEQUANTIZER_OUT*4 - 210)
#define MAX_SCFI                    ((MAX_SCF + 3) & ~3)

#define MINIMP3_MIN(a, b)           ((a) > (b) ? (b) : (a))
#define MINIMP3_MAX(a, b)           ((a) < (b) ? (b) : (a))

#if !defined(MINIMP3_NO_SIMD)

#if !defined(MINIMP3_ONLY_SIMD) && (defined(_M_X64) || defined(__x86_64__) || defined(__aarch64__) || defined(_M_ARM64))
/* x64 always have SSE2, arm64 always have neon, no need for generic code */
#define MINIMP3_ONLY_SIMD
#endif /* SIMD checks... */

#if (defined(_MSC_VER) && (defined(_M_IX86) || defined(_M_X64))) || ((defined(__i386__) || defined(__x86_64__)) && defined(__SSE2__))
#if defined(_MSC_VER)
#include <intrin.h>
#endif /* defined(_MSC_VER) */
#include <immintrin.h>
#define HAVE_SSE 1
#define HAVE_SIMD 1
#define VSTORE _mm_storeu_ps
#define VLD _mm_loadu_ps
#define VSET _mm_set1_ps
#define VADD _mm_add_ps
#define VSUB _mm_sub_ps
#define VMUL _mm_mul_ps
#define VMAC(a, x, y) _mm_add_ps(a, _mm_mul_ps(x, y))
#define VMSB(a, x, y) _mm_sub_ps(a, _mm_mul_ps(x, y))
#define VMUL_S(x, s)  _mm_mul_ps(x, _mm_set1_ps(s))
#define VREV(x) _mm_shuffle_ps(x, x, _MM_SHUFFLE(0, 1, 2, 3))
typedef __m128 f4;
#if defined(_MSC_VER) || defined(MINIMP3_ONLY_SIMD)
#define minimp3_cpuid __cpuid
#else /* defined(_MSC_VER) || defined(MINIMP3_ONLY_SIMD) */
static __inline__ __attribute__((always_inline)) void minimp3_cpuid(int CPUInfo[], const int InfoType)
{
#if defined(__PIC__)
    __asm__ __volatile__(
#if defined(__x86_64__)
        "push %%rbx\n"
        "cpuid\n"
        "xchgl %%ebx, %1\n"
        "pop  %%rbx\n"
#else /* defined(__x86_64__) */
        "xchgl %%ebx, %1\n"
        "cpuid\n"
        "xchgl %%ebx, %1\n"
#endif /* defined(__x86_64__) */
        : "=a" (CPUInfo[0]), "=r" (CPUInfo[1]), "=c" (CPUInfo[2]), "=d" (CPUInfo[3])
        : "a" (InfoType));
#else /* defined(__PIC__) */
    __asm__ __volatile__(
        "cpuid"
        : "=a" (CPUInfo[0]), "=b" (CPUInfo[1]), "=c" (CPUInfo[2]), "=d" (CPUInfo[3])
        : "a" (InfoType));
#endif /* defined(__PIC__)*/
}
#endif /* defined(_MSC_VER) || defined(MINIMP3_ONLY_SIMD) */
static int have_simd(void)
{
#ifdef MINIMP3_ONLY_SIMD
    return 1;
#else /* MINIMP3_ONLY_SIMD */
    static int g_have_simd;
    int CPUInfo[4];
#ifdef MINIMP3_TEST
    static int g_counter;
    if (g_counter++ > 100)
        return 0;
#endif /* MINIMP3_TEST */
    if (g_have_simd)
        goto end;
    minimp3_cpuid(CPUInfo, 0);
    g_have_simd = 1;
    if (CPUInfo[0] > 0)
    {
        minimp3_cpuid(CPUInfo, 1);
        g_have_simd = (CPUInfo[3] & (1 << 26)) + 1; /* SSE2 */
    }
end:
    return g_have_simd - 1;
#endif /* MINIMP3_ONLY_SIMD */
}
#elif defined(__ARM_NEON) || defined(__aarch64__) || defined(_M_ARM64)
#include <arm_neon.h>
#define HAVE_SSE 0
#define HAVE_SIMD 1
#define VSTORE vst1q_f32
#define VLD vld1q_f32
#define VSET vmovq_n_f32
#define VADD vaddq_f32
#define VSUB vsubq_f32
#define VMUL vmulq_f32
#define VMAC(a, x, y) vmlaq_f32(a, x, y)
#define VMSB(a, x, y) vmlsq_f32(a, x, y)
#define VMUL_S(x, s)  vmulq_f32(x, vmovq_n_f32(s))
#define VREV(x) vcombine_f32(vget_high_f32(vrev64q_f32(x)), vget_low_f32(vrev64q_f32(x)))
typedef float32x4_t f4;
static int have_simd()
{   /* TODO: detect neon for !MINIMP3_ONLY_SIMD */
    return 1;
}
#else /* SIMD checks... */
#define HAVE_SSE 0
#define HAVE_SIMD 0
#ifdef MINIMP3_ONLY_SIMD
#error MINIMP3_ONLY_SIMD used, but SSE/NEON not enabled
#endif /* MINIMP3_ONLY_SIMD */
#endif /* SIMD checks... */
#else /* !defined(MINIMP3_NO_SIMD) */
#define HAVE_SIMD 0
#endif /* !defined(MINIMP3_NO_SIMD) */

#if defined(__ARM_ARCH) && (__ARM_ARCH >= 6) && !defined(__aarch64__) && !defined(_M_ARM64)
#define HAVE_ARMV6 1
static __inline__ __attribute__((always_inline)) int32_t minimp3_clip_int16_arm(int32_t a)
{
    int32_t x = 0;
    __asm__ ("ssat %0, #16, %1" : "=r"(x) : "r"(a));
    return x;
}
#else
#define HAVE_ARMV6 0
#endif

typedef struct
{
    const uint8_t *buf;
    int pos, limit;
} bs_t;
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

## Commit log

2023-12-14 Initial snowflake release
    Firmware: 1.0.5
    Hardware: 1.0.1
    [snowflake v1.01 Bom .xls, snowflake-hw-simple-v0.0.1.brd, snowflake-hw-simple-v0.0.1.sch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]
2023-12-23 +Particle Cloud mode function
    Cloud functions are pretty core to the Particle platform so I added a mode function so that the snowflake can change modes and sparkle via cloud.
    Also useful to show off sparkle via the Particle App/Web Console in loud rooms where the voice model currently fails.
    I haven't tested this code yet but except for mode=previous it pretty much copies button presses. Ultimately much of this code should be rolled into RgbStrip but I just wanted to get this in before Christmas!
    [application.cpp]
2023-12-23 Fixed hanging || in application.cpp
    Just removed a hanging || "or"
    [application.cpp]
2023-12-23 fixed mode type in cloudMode case previous
    Added RgbStrip::MODES_T type
    [application.cpp]
2023-12-31 Fix the settings so it can actually store more than 1 item.
    Add the ability to disable the sparkle via the particle console
    - send the content "sparkleEnable:0" to disable the sparkle voice recognition
    Release 1.2.00
    [application.cpp]

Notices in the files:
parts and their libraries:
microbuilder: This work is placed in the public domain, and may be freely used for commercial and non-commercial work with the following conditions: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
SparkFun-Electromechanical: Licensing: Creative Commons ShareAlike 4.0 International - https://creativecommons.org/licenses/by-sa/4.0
